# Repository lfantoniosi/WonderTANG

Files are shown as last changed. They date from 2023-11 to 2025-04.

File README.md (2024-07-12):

# WonderTANG
## TangNano 20K cartridge for MSX computers

This cartridge allows any MSX computer to host a Sipeed Tang Nano 20K. The current fpga core implements:

- MicroSD Nextor 2.1 Drive
- FM OPLL + MSX Music ROM
- 2MB Super Mega RAM SCC+
- 4MB Memory Mapper
- Sega Master System VDP + PSG to allow running SMS roms from SofaRun (Franky HDMI)

## The Super Mega RAM SCC+

The Super Mega RAM SCC+ is a different ACVS-like MegaRam that support different mappers:

- Konami4 (2MB)
- Konami5 SCC+ (512KB)
- ASCII8 (2MB)
- ASCII16 (2MB)

Use the utility SMRAM.COM to allow using different mappers as well activating the SCC+, otherwise it will just work like an ordinary MegaRAM 2MB.

## Board Revisions

The latest available version is [V2.0b](#v20av20b-new). Please, use that version to order new boards.

> [!IMPORTANT]
> Always check your board revision when assembling or programming your WonderTANG.
>
> The revision number is available on the front-left side of the board.
>
> Download the specific [FPGA Bitstream version](#fpga-bitstream-versions) required by your board version.

### [V2.0a/V2.0b (NEW)](https://github.com/lfantoniosi/WonderTANG/tree/4a21359a5136a5a96363da55edc5d934acfd37c5/kicad/)

This is the new version using Tang Nano 20K internal DAC amplifier.

Changes since last revision:
* uses internal DAC for audio output
* switches to a flatter audio connector
* removes jumpers
* requires the latest [FPGA bitstream version](#fpga-bitstream-versions)

V2.0a is equivalent to V2.0b.

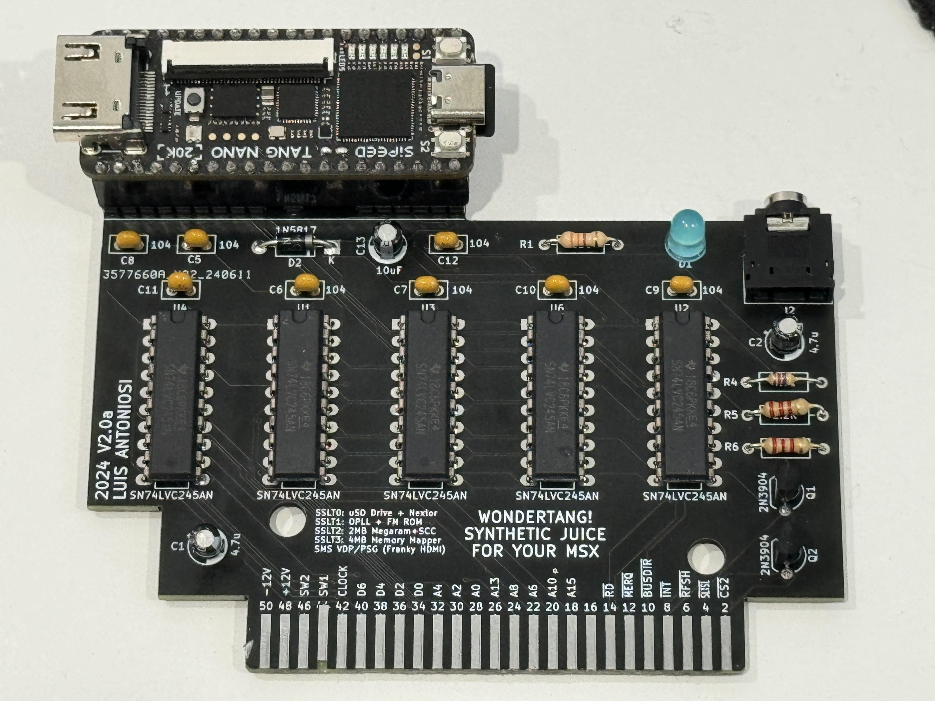
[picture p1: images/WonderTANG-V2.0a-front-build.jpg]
|[](images/WonderTANG-V2.0a-front-build.jpg)|
|:--|
|V2.0a prototype build|

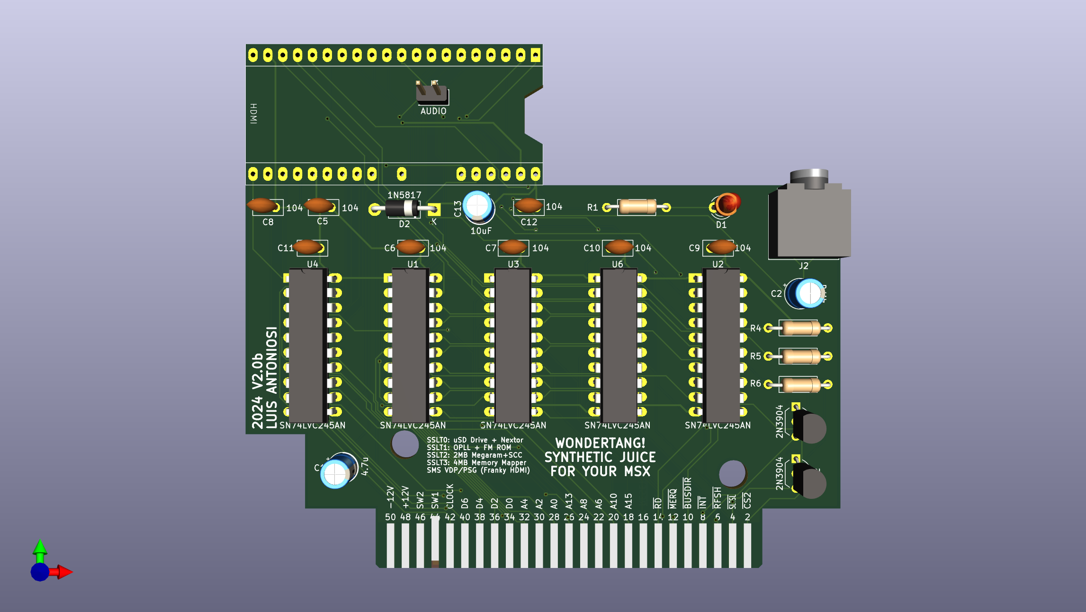
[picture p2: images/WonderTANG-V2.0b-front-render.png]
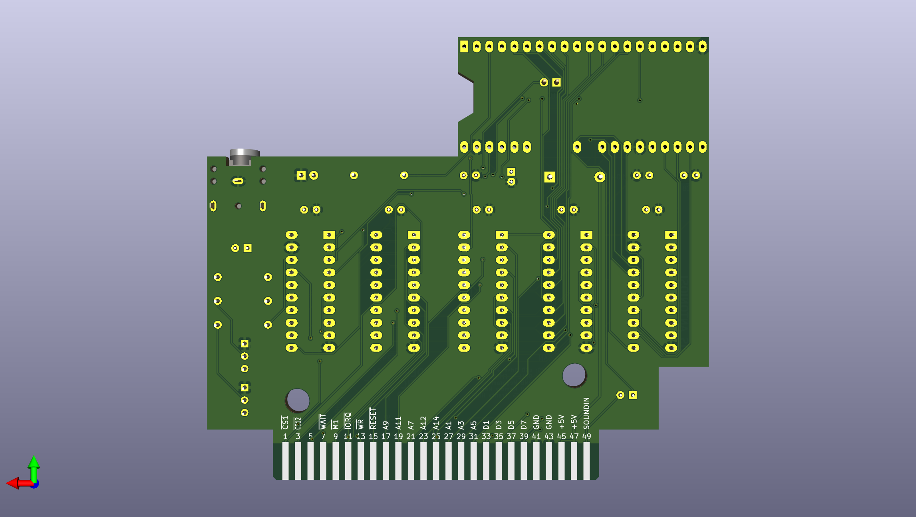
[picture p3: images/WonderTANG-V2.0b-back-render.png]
|[](images/WonderTANG-V2.0b-front-render.png)|[](images/WonderTANG-V2.0b-back-render.png)|
|-|-|
|V2.0b front render|V2.0b back render|

#### PCB

You can access V2.0b gerber files from github at:

[https://github.com/lfantoniosi/WonderTANG/tree/4a21359a5136a5a96363da55edc5d934acfd37c5/kicad/gerber](https://github.com/lfantoniosi/WonderTANG/tree/4a21359a5136a5a96363da55edc5d934acfd37c5/kicad/gerber)

I recommend JLCPCB: https://jlcpcb.com/

#### Bill of Materials

| Reference | Value | Description | Qty | Link |
|---|---|---|-----|---|
| C5, C6, C7, C8, C9, C10, C11, C12 | DIP-100NF | MLCC Monolithic Ceramic Capacitor DIP 100nF (104) | 8 | AliExpress  |
| C1, C2 | ELEC-DIP-4.7UF-16V | Electrolytic Capacitor DIP 4.7uF 16V | 2 | AliExpress  |
| C13 | ELEC-DIP-10UF-16V | Electrolytic Capacitor DIP 10uF 16V | 1 | AliExpress  |
| R5,R6 | DIP-2.2K | Resistor PTH 2.2KR | 2 | Aliexpress  |
| R1 | DIP-330R | Resistor PTH 330R | 1 | AliExpress  |
| R4 | DIP-4.7K | Resistor PTH 4.7KR | 1 | AliExpress  |
| D1 | LED-3MM | LED 3MM Red | 1 | AliExpress  |
| D2 | 1N5817 | SCHOTTKY BARRIER RECTIFIER DIODE | 1 | AliExpress  |
| U1, U2, U3, U4, U6 | SOCKET-DIP-NARROW-20 | DIP Socket Narrow 20 pins | 5 | AliExpress  |
| U1, U2, U3, U4, U6 | SN74LVC245AN | OCTAL BUS TRANSCEIVER WITH 3-STATE OUTPUTS | 5 | See note |
| Q1,Q2 | 2N3904 | 2N3904 NPN switching Transistor | 2 | AliExpress  |
| J2 | CP1-3523N | CONN JACK STEREO 3.5MM R/A | 1 | AliExpress  |
| J3 | Mini Micro male/female JST | Mini Micro male/female JST | 1 | AliExpress  |
| U5 | Tang Nano 20K | Tang Nano 20K | 1 | AliExpress  |

#### Build Notes

The audio J3 needs to be soldered into the TANG Nano 20K speaker pins (two small pins between the words SiPEED and TANG NANO 20K, polarity does not matter). Use the JST connector or solder it directly under the board.

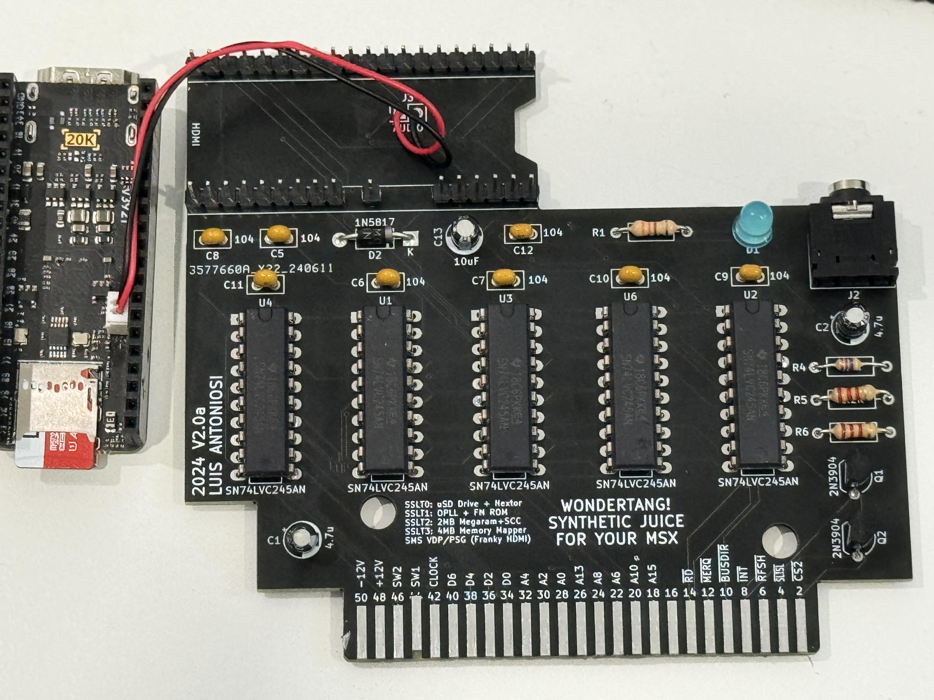
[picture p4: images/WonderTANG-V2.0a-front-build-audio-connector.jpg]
[](images/WonderTANG-V2.0a-front-build-audio-connector.jpg)

#### 74LVC245AN

Be aware of fake 74VLC245 sold from Chinese vendors like AliExpress or UTSource. There are reports of they being 74LS245 rebranded as LVC which does not work. You need genuine 75LVC245. Buy then from DigiKey, Mouser or Adafruit.

### [V1.02d (PREVIOUS)](https://github.com/lfantoniosi/WonderTANG/tree/0e938fb70acad34c753a95fd54bb3fdd6095d590/kicad/)

> [!WARNING]
> If you are building new boards, please use the latest available board revision instead.

This version fixes a problem with Philips MSX machines (detected on [Philips VG8235](https://www.msx.org/wiki/Philips_VG-8235) and [Philips NMS8245](https://www.msx.org/wiki/Philips_NMS_8245)) by properly implementing the MSX cartridge nINT signal as an open-collector.

Changes since last revision:
* uses a transistor to implement nINT as open-collector
* requires a specific [FPGA bitstream version](#fpga-bitstream-versions)

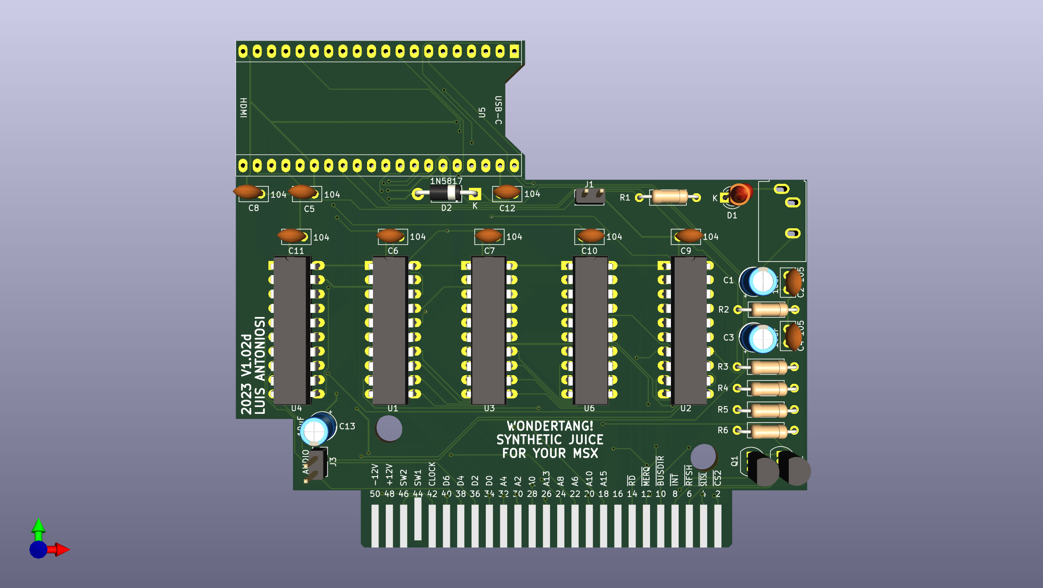
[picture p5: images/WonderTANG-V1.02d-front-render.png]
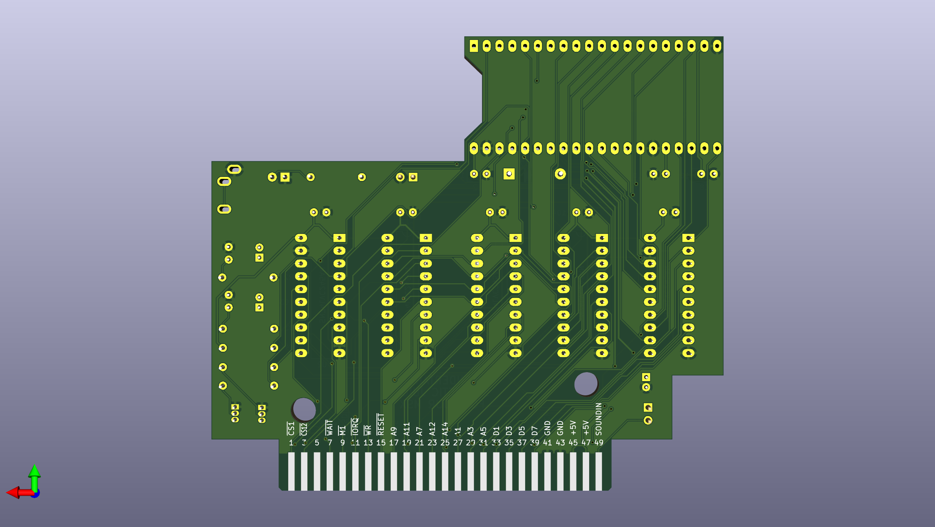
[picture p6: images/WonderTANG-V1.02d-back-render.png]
|[](images/WonderTANG-V1.02d-front-render.png)|[](images/WonderTANG-V1.02d-back-render.png)|
|-|-|
|V1.02d front render|V1.02d back render|

#### PCB

You can access V1.02d gerber files from github at:

[https://github.com/lfantoniosi/WonderTANG/tree/0e938fb70acad34c753a95fd54bb3fdd6095d590/kicad/gerber](https://github.com/lfantoniosi/WonderTANG/tree/0e938fb70acad34c753a95fd54bb3fdd6095d590/kicad/gerber)

#### Bill of Materials

| Reference | Value | Description | Qty | Link |
|---|---|---|-----|---|
| C5, C6, C7, C8, C9, C10, C11, C12 | DIP-100NF | MLCC Monolithic Ceramic Capacitor DIP 100nF (104) | 8 | AliExpress  |
| C1, C3, C13 | ELEC-DIP-10UF-16V | Electrolytic Capacitor DIP 10uF 16V | 3 | AliExpress  |
| C2, C4 | DIP-1UF | MLCC Monolithic Ceramic Capacitor DIP 1uF (105) | 2 | AliExpress  |
| R2, R3 | DIP-47R | Resistor PTH 47R | 2 | AliExpress  |
| R5,R6 | DIP-2.2K | Resistor PTH 2.2KR | 2 | Aliexpress  |
| R1 | DIP-330R | Resistor PTH 330R | 1 | AliExpress  |
| R4 | DIP-4.7K | Resistor PTH 4.7KR | 1 | AliExpress  |
| D1 | LED-3MM | LED 3MM Red | 1 | AliExpress  |
| D2 | 1N5817 | SCHOTTKY BARRIER RECTIFIER DIODE | 1 | AliExpress  |
| U1, U2, U3, U4, U6 | SOCKET-DIP-NARROW-20 | DIP Socket Narrow 20 pins | 5 | AliExpress  |
| U1, U2, U3, U4, U6 | SN74LVC245AN | OCTAL BUS TRANSCEIVER WITH 3-STATE OUTPUTS | 5 | See note above  |
| Q1,Q2 | 2N3904 | 2N3904 NPN switching Transistor | 2 | AliExpress  |
| C13 | ELEC-DIP-10UF-16V | Electrolytic Capacitor DIP 10uF 16V | 1 | AliExpress  |
| C1, C2 | ELEC-DIP-4.7UF-16V | Electrolytic Capacitor DIP 7.7uF 16V | 2 | AliExpress  |
| J1, J3 | PH-254-S-M-40-BLACK | 2.54mm 1 x 40 Pin Male Single Row Pin Header Strip Black | 1 | AliExpress  |
| J2 | SJ1-3533NG | SJ1-3533NG Audio P4 3 Pin connector | 1 | AliExpress  |
| U5 | Tang Nano 20K | Tang Nano 20K | 1 | AliExpress  |

### [V1.01c (OBSOLETE)](https://github.com/lfantoniosi/WonderTANG/tree/b9e608418bb1917098046716af13b877def6737b/kicad/)

> [!WARNING]
> If you are building new boards, please use the latest available board revision instead.

This version corrects an audio problem due to wrong connection of AUDIO and SOUNDIN capacitors.

Changes since last revision:
* fix audio output
* requires an old [FPGA bitstream version](#fpga-bitstream-versions)

> [!IMPORTANT]
> This version is known to experience problems with some Philips MSX machines.

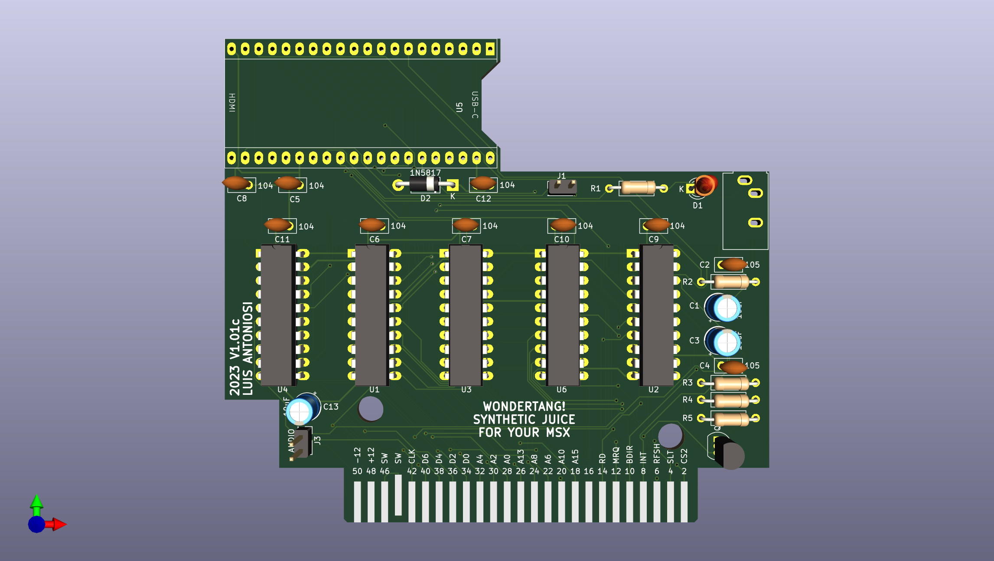
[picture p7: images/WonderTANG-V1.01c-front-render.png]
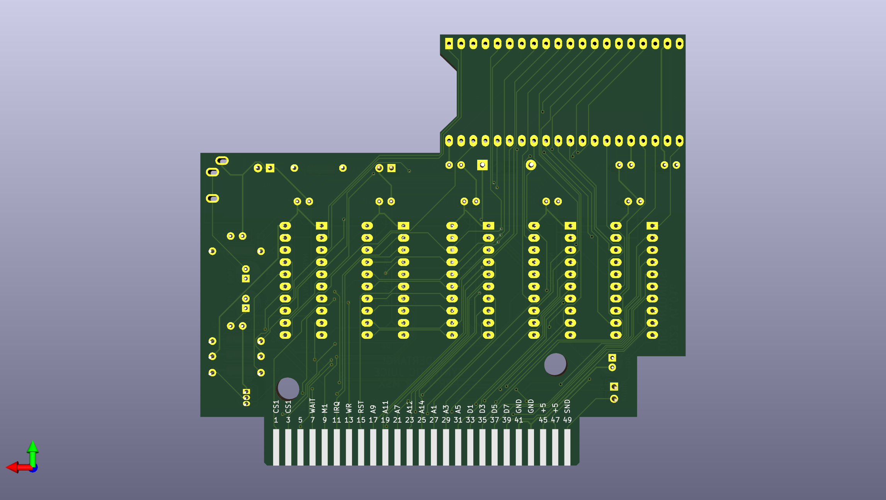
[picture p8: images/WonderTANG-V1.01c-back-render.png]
|[](images/WonderTANG-V1.01c-front-render.png)|[](images/WonderTANG-V1.01c-back-render.png)|
|-|-|
|V1.01c front render|V1.01c back render|

#### PCB

You can access V1.01c gerber files from github at:

[https://github.com/lfantoniosi/WonderTANG/tree/b9e608418bb1917098046716af13b877def6737b/kicad/gerber](https://github.com/lfantoniosi/WonderTANG/tree/b9e608418bb1917098046716af13b877def6737b/kicad/gerber)

Or you can order V1.01c PCBs directly from:

[https://www.pcbway.com/project/shareproject/WonderTANG_v1_01c_ba2c16ea.html](https://www.pcbway.com/project/shareproject/WonderTANG_v1_01c_ba2c16ea.html)

<a href="https://www.pcbway.com/project/shareproject/WonderTANG_v1_01c_ba2c16ea.html">PCB from PCBWay</a>

A small part of the money will be donated to the author of the project.

#### Bill of Materials

| Reference | Value | Description | Qty | Link |
|---|---|---|-----|---|
| C5, C6, C7, C8, C9, C10, C11, C12 | DIP-100NF | MLCC Monolithic Ceramic Capacitor DIP 100nF (104) | 8 | AliExpress  |
| C1, C3, C13 | ELEC-DIP-10UF-16V | Electrolytic Capacitor DIP 10uF 16V | 3 | AliExpress  |
| C2, C4 | DIP-1UF | MLCC Monolithic Ceramic Capacitor DIP 1uF (105) | 2 | AliExpress  |
| R2, R3 | DIP-47R | Resistor PTH 47R | 2 | AliExpress  |
| R1 | DIP-330R | Resistor PTH 330R | 1 | AliExpress  |
| R4 | DIP-4.7K | Resistor PTH 4.7KR | 1 | AliExpress  |
| R5 | DIP-2.2K | Resistor PTH 2.2KR | 1 | |
| D1 | LED-3MM | LED 3MM Red | 1 | AliExpress  |
| D2 | 1N5817 | SCHOTTKY BARRIER RECTIFIER DIODE | 1 | AliExpress  |
| U1, U2, U3, U4, U6 | SOCKET-DIP-NARROW-20 | DIP Socket Narrow 20 pins | 5 | AliExpress  |
| U1, U2, U3, U4, U6 | SN74LVC245AN | OCTAL BUS TRANSCEIVER WITH 3-STATE OUTPUTS | 5 | See note above  |
| Q1 | 2N3904 | 2N3904 NPN switching Transistor | 1 | AliExpress  |
| J1, J3 | PH-254-S-M-40-BLACK | 2.54mm 1 x 40 Pin Male Single Row Pin Header Strip Black | 1 | AliExpress  |
| J2 | SJ1-3533NG | SJ1-3533NG Audio P4 3 Pin connector | 1 | AliExpress  |
| U5 | Tang Nano 20K | Tang Nano 20K | 1 | AliExpress  |

### [V1.01b (OBSOLETE)](https://github.com/lfantoniosi/WonderTANG/tree/09ee5923f52284835864b947fba076c70dbe0fab/kicad/)

### [V1.01 (OBSOLETE)](https://github.com/lfantoniosi/WonderTANG/tree/d6cbb30488c2db2edb72d424ac75a0af0b1afaa3/kicad/)

### [V1.0 (OBSOLETE)](https://github.com/lfantoniosi/WonderTANG/tree/ac242e77184eeba1786766e48963c7b3fef0f877/kicad/)

## FPGA Bitstream Versions

If you want to program your WonderTANG you need to download the specific FPGA bitstream for your board revision according to the following table.

| Board Revision | FPGA Bitstream File |
| --- | --- |
| V1.0 | [WonderTANG_v1.0-v1.01c.fs](https://github.com/lfantoniosi/WonderTANG/blob/main/fpga/impl/pnr/WonderTANG_v1.0-v1.01c.fs?raw=True) |
| V1.01 | [WonderTANG_v1.0-v1.01c.fs](https://github.com/lfantoniosi/WonderTANG/blob/main/fpga/impl/pnr/WonderTANG_v1.0-v1.01c.fs?raw=True) |
| V1.01b | [WonderTANG_v1.0-v1.01c.fs](https://github.com/lfantoniosi/WonderTANG/blob/main/fpga/impl/pnr/WonderTANG_v1.0-v1.01c.fs?raw=True) |
| V1.01c | [WonderTANG_v1.0-v1.01c.fs](https://github.com/lfantoniosi/WonderTANG/blob/main/fpga/impl/pnr/WonderTANG_v1.0-v1.01c.fs?raw=True) |
| V1.02d | [WonderTANG_v1.02d.fs](https://github.com/lfantoniosi/WonderTANG/blob/main/fpga/impl/pnr/WonderTANG_v1.02d.fs?raw=True) |
| V2.0b | [WonderTANG.fs](https://github.com/lfantoniosi/WonderTANG/blob/main/fpga/impl/pnr/WonderTANG.fs?raw=True) |

## Programming the Cartridge

### How to Program the Tang Nano 20K from Windows

Install the Gowin Educative IDE or just the programmer if you want to just flash the files on your board. You can install it from https://www.gowinsemi.com/ by providing your personal data and registering. Please reboot your computer after installing the drivers.

Connect your TangNano board to the computer USB and open the Gowin Programmer software. Please note that we will be just programming the board, so you will not effectively use the IDE at this time. You should see the following message indicating that your board/cable was recognized. 

NOTE: for version 2.0b the FPGA core re-uses JTAG pins. So once flashed to re-flash the tang you need to press S1 button on it before connecting the USB-C cable and keep it pressed during all the time of the flashing process.

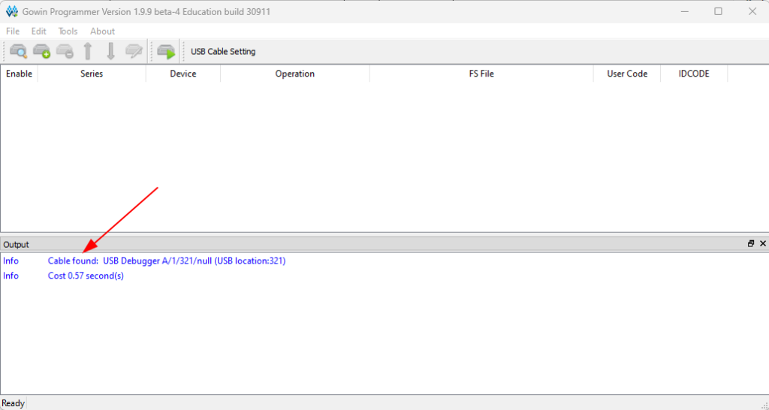
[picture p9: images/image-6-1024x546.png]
Cable Detected


Click Add Device. You will see a new device on the list. Click on the Series and select GW2AR.

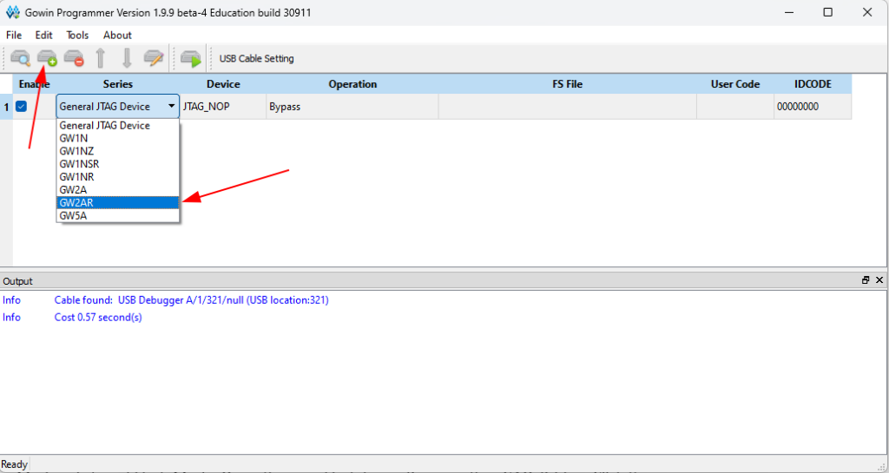
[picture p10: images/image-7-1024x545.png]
Device Selection


Now double click the device on the list and set Access Mode = External Flash Mode, Operation = exFlash Erase, Program thru GAO-Bridge. Click the elipsis and **select the __specific .fs file__ for your WonderTANG board revision** (see [FPGA bitstream versions](#fpga-bitstream-versions)). Select Generic Flash as the Device and make sure the address 0x000000 is selected. Click Save.

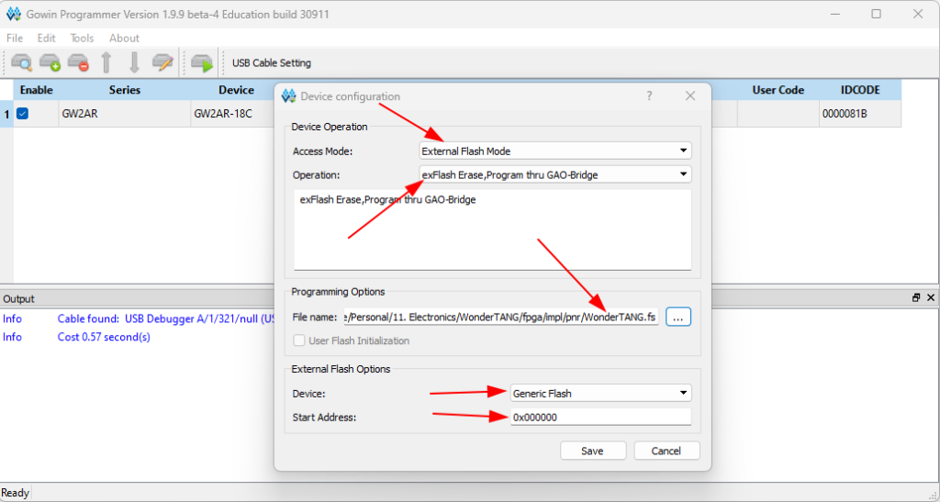
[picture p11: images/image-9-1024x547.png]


Click Add Device again. Set the Series to GW2AR. Double click on the device and set Access Mode = External Flash Mode, select Operation = exFlash C Bin Erase, Program thru GAO-Bridge. Click the elipsis and select the Nextor-2.1.1.WonderTANG.ROM.bin file. Select Generic Flash as the Device and make sure the address 0x100000 is selected. Click Save.

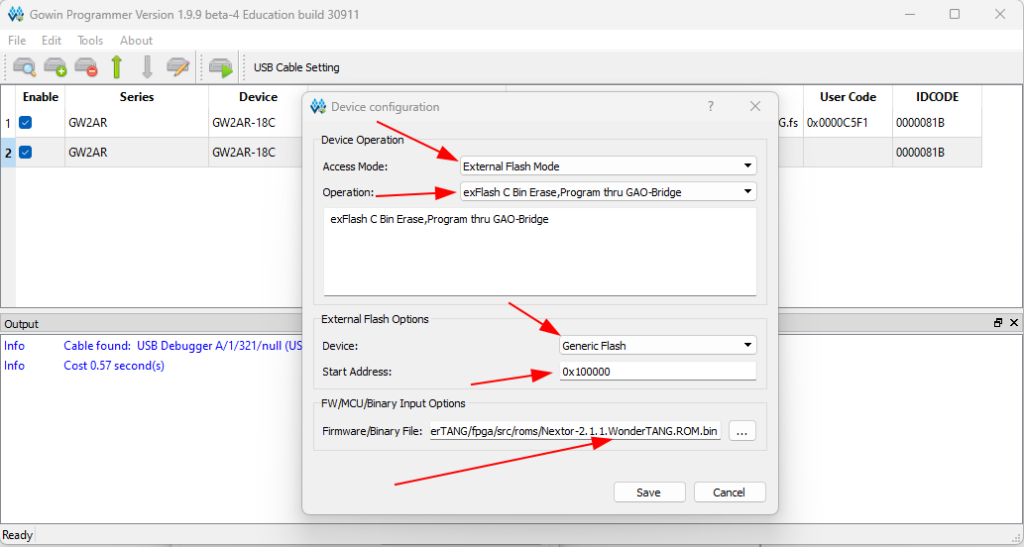
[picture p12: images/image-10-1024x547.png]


Now Enable just the first device on the list, go to the Edit menu and select Program/Configure (or click the program button).

<div style="display: flex; justify-content: space-between;">
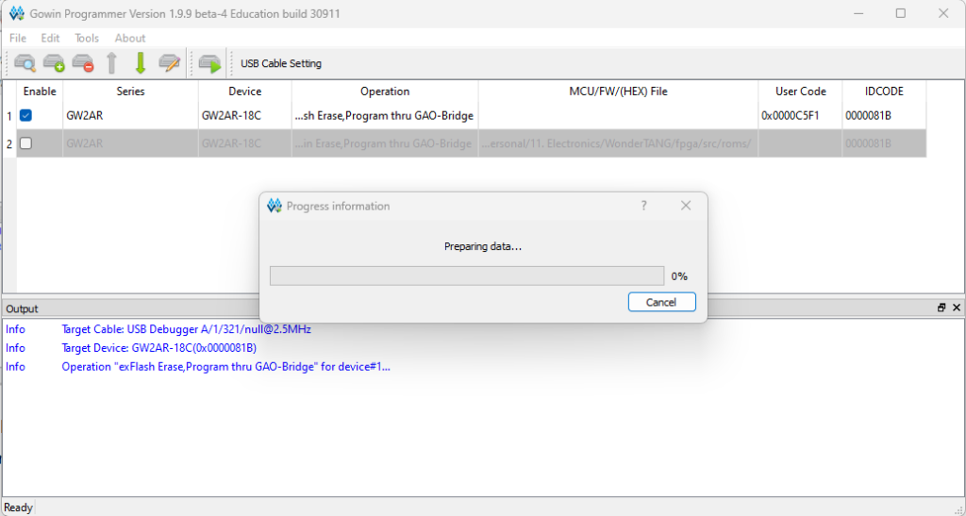
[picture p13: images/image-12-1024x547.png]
     &nbsp;
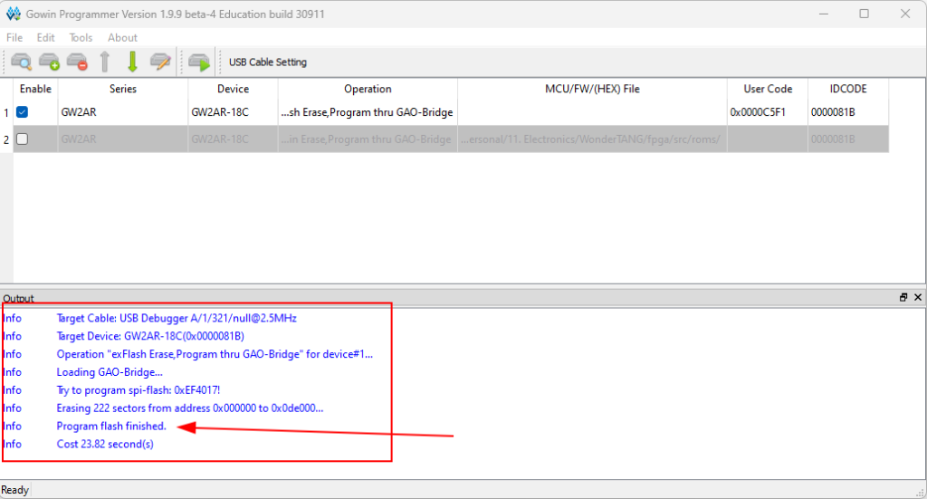
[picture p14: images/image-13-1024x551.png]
    
</div>
&nbsp;

Repeat the steps now enabling just the second device on the list. That will save the BIOS on the flash.

<div style="display: flex; justify-content: space-between;">
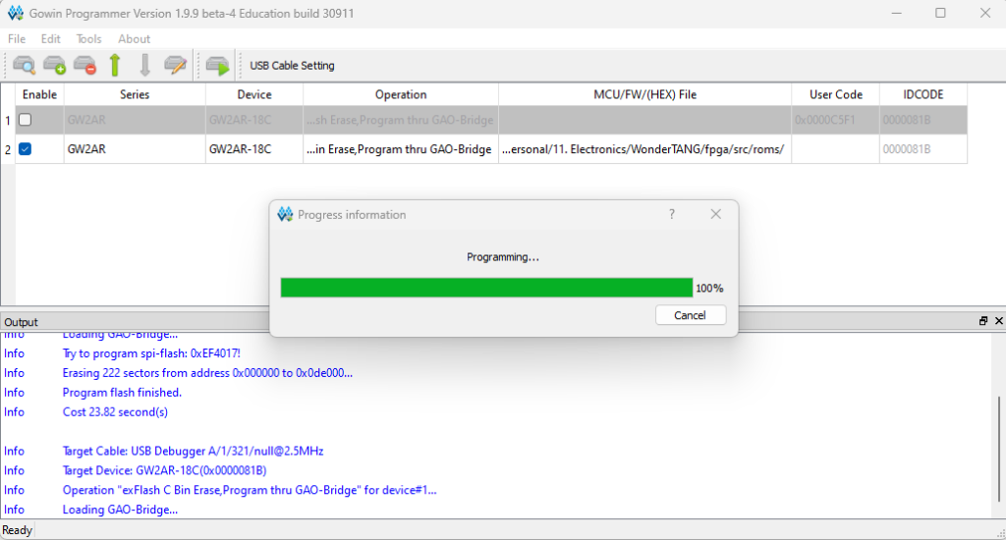
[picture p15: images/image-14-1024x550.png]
     &nbsp;
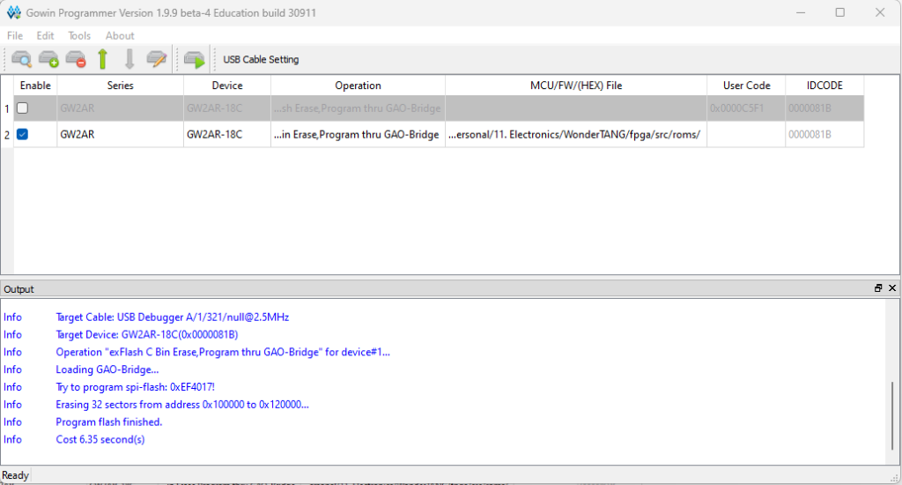
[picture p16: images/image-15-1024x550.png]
    
</div>
&nbsp;

### How to Program the Tang Nano 20K from Linux

As the native programmer of the Gowin IDE does not properly work in Linux, it is recommended to use [openFPGALoader](https://github.com/trabucayre/openFPGALoader) to program the Tang Nano 20K of the WonderTANG.

This procedure has been tested successfully using openFPGALoader v0.10.0.

Assuming that you already downloaded **the __specific .fs file__ for your WonderTANG board revision** (see [FPGA bitstream versions](#fpga-bitstream-versions)) and `Nextor-2.1.1.WonderTANG.ROM` files, and that your Tang Nano 20K is connected to your computer using a USB cable, you can proceed as follows:

* Upload the bitstream (in this case `path_to_your/WonderTANG/fpga/impl/pnr/WonderTang.fs`) using the following command:

```
openFPGALoader -f -b tangnano20k --external-flash path_to_your/WonderTANG/fpga/impl/pnr/WonderTANG.fs
```

* Upload the WonderTANG ROM file `path_to_your/WonderTANG/kernel/Tang/Nextor-2.1.1.WonderTANG.ROM` using the following command:

```
openFPGALoader -f -b tangnano20k --external-flash -o 1048576 path_to_your/WonderTANG/kernel/Tang/Nextor-2.1.1.WonderTANG.ROM
```

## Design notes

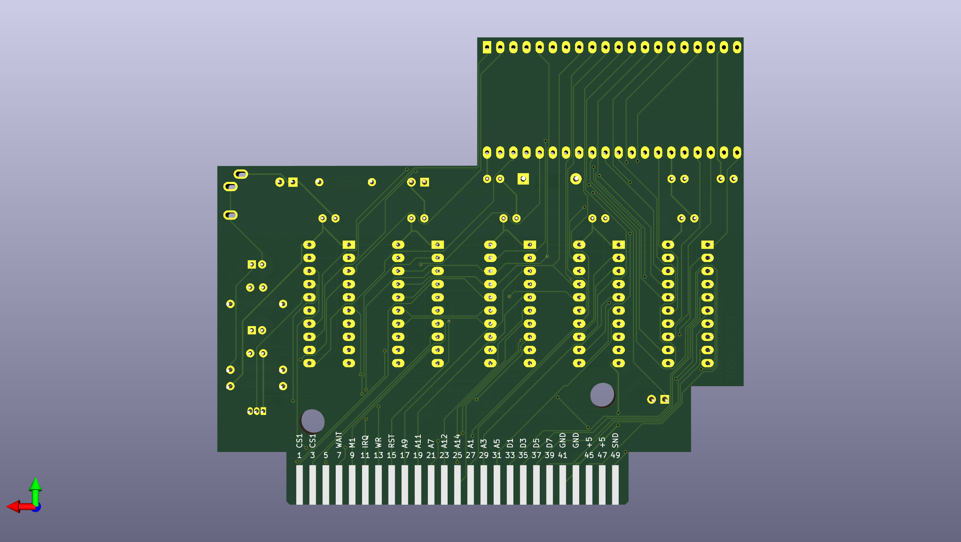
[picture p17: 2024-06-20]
images/WonderTANG-V1.01-back-render.png

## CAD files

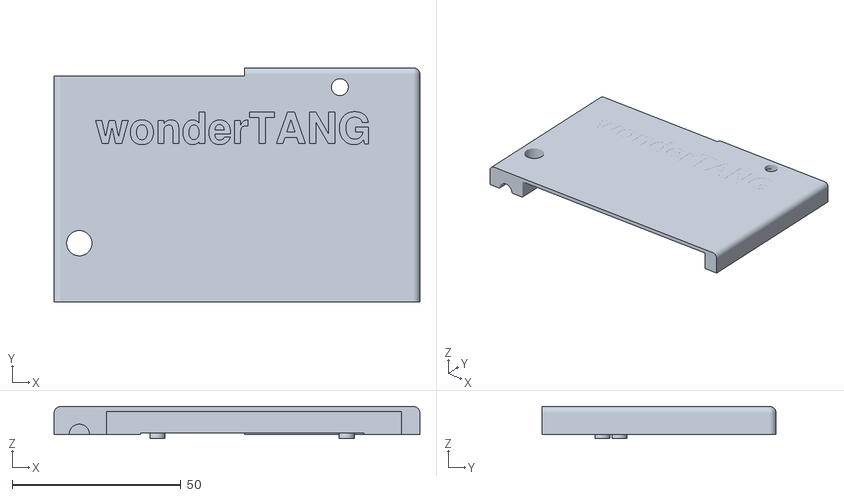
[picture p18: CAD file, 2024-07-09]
case/wonderTANGv2-cart-top.stl
108.5 x 69.5 x 9.50

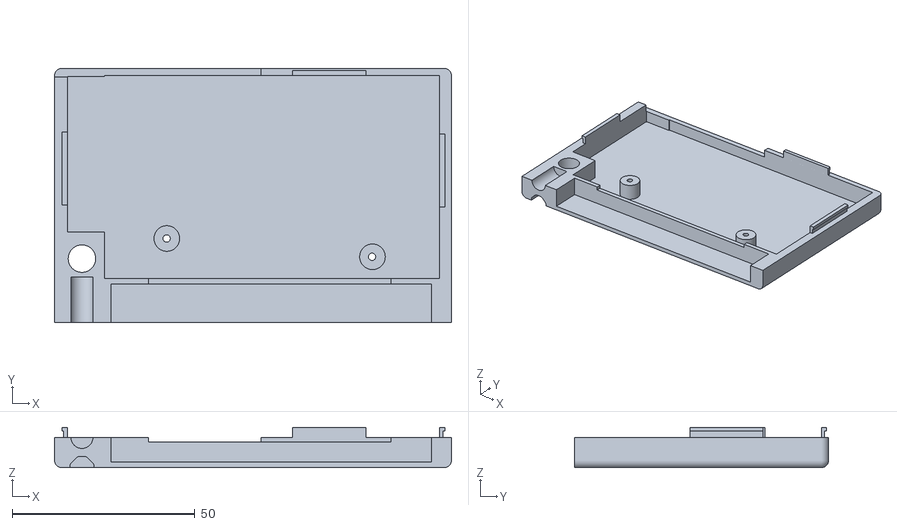
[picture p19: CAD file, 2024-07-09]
case/wonderTANGv2-cart-bottom.stl
108.5 x 69.5 x 11.0

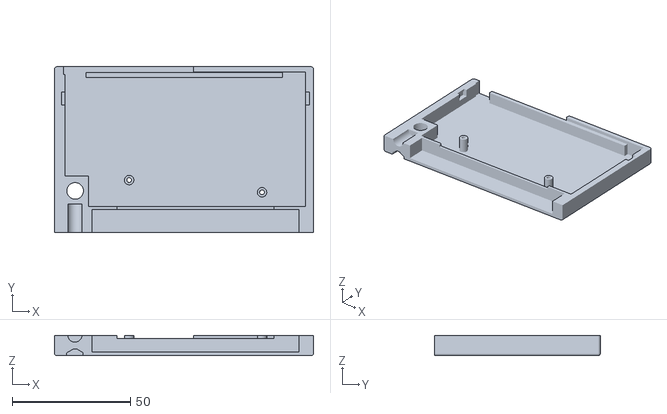
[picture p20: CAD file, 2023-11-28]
case/bottom.stl
109.5 x 70.0 x 8.66

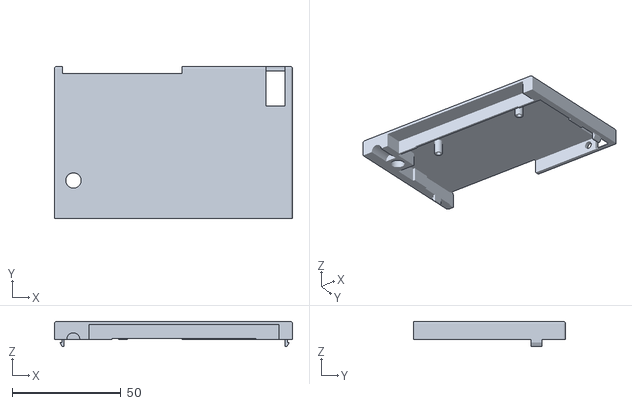
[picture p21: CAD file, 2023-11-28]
case/top.stl
109.5 x 70.0 x 11.6

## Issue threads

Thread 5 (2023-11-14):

sd_reader and BUFG

siriokds, 2023-11-14:
Hi! I wonder if I could use the sd_reader module on a TN9K. The SD card pinout on the 20K has a different pin configuration. What do you think?

Another question is, is BUFG verilog instruction available even on VHDL? Is it a native language feature?

Nice job, thanks.

lfantoniosi, 2023-11-14:
Yes it should work just set map the correct pins.

I don’t know why you want to make a new design in VHDL but yet they are
there. Go for gowin bufg on google and get the pdf from gowin. You l need
to declare the module.

On Mon, Nov 13, 2023 at 10:58 PM Saverio Russo ***@***.***>
wrote:

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

siriokds, 2023-11-14:
> Yes it should work just set map the correct pins. I don’t know why you want to make a new design in VHDL but yet they are there. Go for gowin bufg on google and get the pdf from gowin. You l need to declare the module.
> […](#)
> On Mon, Nov 13, 2023 at 10:58 PM Saverio Russo ***@***.***> wrote: Hi! I wonder if I could use the sd_reader module on a TN9K. The SD card pinout on the 20K has a different pin configuration. What do you think? Another question is, is BUFG verilog instruction available even on VHDL? Is it a native language feature? Nice job, thanks. — Reply to this email directly, view it on GitHub <#5>, or unsubscribe <https://github.com/notifications/unsubscribe-auth/ACCJWU7RYFVLHGRB7T3TNMTYEMJAPAVCNFSM6AAAAAA7KJWXDWVHI2DSMVQWIX3LMV43ASLTON2WKOZRHE4TEMJQHEYTMMQ> . You are receiving this because you are subscribed to this thread.Message ID: ***@***.***>

Thank for quick reply.
I'm not familiar with verilog but 15 years of vhdl. Not yet converted myself to verilog or system verilog.

About SD card, the 9K has only 4 pins connected as far as I saw on the schematic and the DAT1 and DAT2 are not connected.
I don't know if they must be connected to switch to SDIO instead SPI (do your sd_reader uses SDIO ?).

Btw have you faced some design flaw in 9K board? I don't know why but looks a bit noisy.

lfantoniosi, 2023-11-15:
The sd reader uses sdbus, no spi. It's derived from the sd_reader from
internet i just added write routines to it. Some people reported
success using the internet sd reader for 9k so using my version should
not be a problem.

The design flaw is to have HDMI EDID vcc connected to the board VCC.

On Tue, Nov 14, 2023 at 4:27 AM Saverio Russo ***@***.***>
wrote:

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

--
Luis Felipe Antoniosi

siriokds, 2023-11-15:
Probably I will switch to 20K as well, I don't realize if my code isn't
good or it's a board issue.
I need to learn verilog, looks like similar to c-like languages.
I found all documents about gowin primitives thank you.

I used to coding on altera FPGA before the prices rose up

Il mer 15 nov 2023, 09:51 lfantoniosi ***@***.***> ha scritto:

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

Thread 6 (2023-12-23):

How to program Tang Nano 20K

atssada, 2023-12-23:
Hello,

Literally wonderful project you made!
Really appreciated to have a chance to enjoy your masterpiece!

By the way, I am not familiar with Gowin Programmer...

How can I program Wondertang correctly?

Is it enough to program "\fpga\src\roms\Nextor-2.1.1.WonderTANG.ROM.bin"?

I could manage above bin file via Gowin Programmer, but found nothing happened in my MSX(Toshiba HX-10DP, and FS-A1).

I am pretty sure I could solder all necessary parts in the pcb..

Sorry for cumbersome question..

Have a great day!

lfantoniosi, 2023-12-23:
Hi,

You need to program the .fs file inside the impl folder as flash program
generic flash and the the .bin as cbin at address 0x100000 just like is
shown to the readme

The bin file is just the nextor rom not the fpga.

Luis Felipe Antoniosi

On Fri, Dec 22, 2023 at 8:16 PM Jinyong Kim ***@***.***>
wrote:

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

atssada, 2023-12-26:
Thank you very much for kind explanation..

Still I have issue. :)

And this is my reproduction steps, hope you can find any advice..

----

1. Programming WonderTANG.fs

External Flash Mode
exFlash Erase,Program thru GAO-Bridge
Generic Flash
0x000000

2. Programming Nextor-2.1.1.WonderTANG.ROM.bin

External Flash Mode
exFlash Erase,Program thru GAO-Bridge
Generic Flash
0x100000

3. Prepare SD Card

Restore MSX Nextor Bootable VHD image(4GB) to SanDisk 32GB SD Card by using HDD Raw Copy Tool

https://download.file-hunter.com/Archive/MISTICA%20MSX%20VHD%20%5B25-03-2019%5D.zip

https://hddguru.com/software/HDD-Raw-Copy-Tool

4. Insert SD Card To Tang Nano 20K, and power on of MSX..

HDMI TV is showing black screen (turning into black screen from "no-signal")

lfantoniosi, 2023-12-27:
ok I think you are getting some confusion there. First, use a blank SD and
use the call FDISK from basic to create a 4GB partition or smaller.

The hdmi output is *ONLY* for the SMS (MASTER SYSTEM VDP). It won't display
anything for the MSX. For this you use the same output you have.

Check if the msx boots if it shows the wondertang message, detect sd card
and etc.

Once you had the card formatted in FDISK you can copy using a PC the files
to it.

On Mon, Dec 25, 2023 at 4:47 PM Jinyong Kim ***@***.***>
wrote:

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

--
Luis Felipe Antoniosi

cristianoag, 2023-12-30:
Step 2 needs to be Access Mode = External Flash Mode, select Operation = exFlash C Bin Erase, Program thru GAO-Bridge. Click the elipsis and select the Nextor-2.1.1.WonderTANG.ROM.bin file. Select Generic Flash as the Device and make sure the address 0x100000 is selected.

However, I noticed that 1.01 version is driving WAIT to low all the times. Check the transistor and it is shorted to ground with both collector and emitter to GND. Checked the latest circuit and saw there is a 2k2 resistor and a few changes to the transistor footprint connections. Implemented those on my PCB via bodge wires, but no success... the MSX is waiting with WAIT in low all the times. It lookes like the Tang is not executing anything.

lfantoniosi, 2023-12-31:
There was a bug on previous boards. You should follow the new schematic if
you printed an earlier board. The transistor should not have short circuits.

Luis Felipe Antoniosi

On Sat, Dec 30, 2023 at 3:56 PM Cristiano Goncalves <
***@***.***> wrote:

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

cristianoag, 2023-12-31:
I just created a pull request changing the README file to include detailed steps on how to program the Tang Nano. I also included a few images and removed the lock file that was generating a message every time that the project was being opened on kicad. @lfantoniosi upload the gerbers to a shared project on PCBWAY and update the link I included to point to there... you will receive some cash back for your effort. Same with the AliExpress affiliated purchase links.

atssada, 2024-01-13:
@lfantoniosi

Thank you so much for kind additional explanation..

I found my faulty buffer logic ic that I bought from Aliexpress, and I solved the issue with the good ic that I bought from Digikey.

MegaRam, Mapper works flawlessly! Let me enjoy more feature of your wonderful gear.

@cristianoag

Thank you so much for wonderful level of easy & straight forward programming manual. :)

atssada, 2024-01-13:
Thank you so much!

lfantoniosi, 2024-01-13:
glad it is working. check out the sega master system roms from sofarun
ssms.com

I put some patches here:

https://msx.org/forum/msx-talk/general-discussion/franky-ssmscom-patches-where-are-they?page=0

On Fri, Jan 12, 2024 at 5:10 PM Jinyong Kim ***@***.***>
wrote:

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

--
Luis Felipe Antoniosi

Closed 2024-01-13.

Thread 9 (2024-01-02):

TangNano is driving 3.3V on pin 36 (WAIT_33)

cristianoag, 2024-01-02:
The board lokks like is functioning adequately; however, there is a persistent issue with the Tang, consistently delivering 3.3V to pin 36. The transistor, intended to serve as a NOT gate for that line, is erroneously driving GND/0 to the Z80, consequently blocking the proper functioning of the MSX. I have attempted with two TangNano boards without success. Has anyone, aside from Felipe, successfully achieved compatibility with the latest PCB and code versions for this board?

lfantoniosi, 2024-01-02:
what version are you using? there is a pullup resistor for this line (R4).
The tang should put this line to GND. look this line:

assign wait_n = (ff_wait || ~reset_ram_n) ? 1'b1 : 1'b0;

is either 1 or 0. Previous versions of the fpga would put it to Z. You
don't want it to be Z. So use the latest code available.

On Tue, Jan 2, 2024 at 12:53 PM Cristiano Goncalves <
***@***.***> wrote:

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

--
Luis Felipe Antoniosi

lfantoniosi, 2024-01-02:
the wait line is an open collector and should remain GND at startup. So the
transistor opens at the boot and closes forever after disconnecting the line

On Tue, Jan 2, 2024 at 2:05 PM Luis F. Antoniosi ***@***.***>
wrote:

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

--
Luis Felipe Antoniosi

cristianoag, 2024-02-28:
Problem was being caused by bad chips from AliExpress.

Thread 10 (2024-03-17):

Wondertang on the Omega Home Computer

herraa1, 2024-03-17:
First of all thanks a lot for your MSX-related projects, and thanks again for publishing them, I really enjoy them.

Now striaght to the issue...

I've built a WonderTANG and it works wonderfully on most of my real MSX computers (scc, megaram and sms):
- Sony HB-501F OK
- Toshiba HX-10 OK
- Panasonic FS-A1WSX OK
- Sony HB-101P, the boot screen shows up but it looks like the embedded firmware in this machine causes some incompatibility (can reach Basic by pressing CTRL-SHIFT-CODE-GRAPH and then "screen0", but issuing "call system" goes to basic again and again instead of entering Nextor)
- Philips VG-8235, it boots to Nextor prompt but (I'm not sure) either the system freezes or the keyboard doesn't work as can't type anything (I need to do more testing here...)

But trying to use the WonderTANG on my Omega Home Computer always produces problems:
- the boot screen always shows up and recognizes the sd card properly
- but it can get stuck into a boot loop
- or video characters may appear slightly corrupted on the WonderTANG boot screen
- or if it manages to boot properly to nextor, then "call fdisk" terminates after a while if I stop pressing some keys (as if the Esc key was magically pressed)
- or system freezes when accessing the sd card and ends up corrupting it sometimes

I've checked that the WonderTANG receives proper +5V: I have even added a bypass jumper to the diode protecting the MSX from been powered by the USB port from the WonderTANG (I do not power it from USB while inserted on the MSX) to avoid the voltage diode voltage drop (which makes it a bit more stable, but not enough anyway).

My Omega works OK with all software and hardware I've tested (demos, disk games, game cartridges, rookie drive, flashjacks, tsxduino, ...) except for the WonderTANG.

My Omega uses HCT chips as recommended on the official BoM, and has only 512KB of RAM, no RAM extension.
The only addons I have are:
- a floppy disk controller HAT based on the CX-2, but I've uninstalled it with no changes regarding the WonderTANG
- an audio amplifier, but I've disconnected it with no changes regarding the WonderTANG

I don't know where the problem lays between the Omega and the WonderTANG.

Something I've noticed is that when the WonderTANG is inserted into the Omega and I raise a lot the volume of the audio amplifier I can hear a lot more noises than the "usual" ones from the Omega when no WonderTANG is inserted.

Have you tried your WonderTANG on your Omega Home Computer?
Does it work for you?
Any clues on why mine's doesn't properly work?

Thanks a lot!

lfantoniosi, 2024-03-18:
I didn't try because my omega is without a power supply.

If you look to any MSX implementation the wait line connects directly to
the Z-80 halting it when low. On omega it goes to a SLPD (slot dir) where
it adds VDP wait, KDB wait and M1 wait.

Wait is an open collector, I don't know if this SPLD is preserving it. I
didn't look ot other MSX2+ implementations to compare.

Luis Felipe Antoniosi

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

lfantoniosi, 2024-03-18:
Can you disconnect the wait line (remove transistor) and test it on both
machines?

Luis Felipe Antoniosi

On Sun, Mar 17, 2024 at 10:41 PM Luis F. Antoniosi <
***@***.***> wrote:

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

herraa1, 2024-03-18:
I desoldered the transistor Q1 and tried again with the Toshiba HX-10 and the Omega.

The Toshiba HX-10 no longer works ok (it behaves now like the Sony HB-101P in the previous test):
- the system boots and shows the WonderTANG boot info, detecting the SD card
- it asks for the date and enters Basic
- the Basic info shows that there is MSX Basic 1.0 and Disk Basic 1.0 (so the WonderTANG adds the disk Basic)
- when you try a "call system" it re-enters Basic again, no Nextor
- if you try a "files" it displays "Disk I/O error" and returns to the Basic prompt

The Omega doesn't work either.
- the system boots and shows the WonderTANG boot info, detecting the SD card
- sometimes it freezes during the boot process
- sometimes it manages to load Nextor
- sometimes it boots to basic instead of Nextor
- if it manages to load Nextor, a "dir" completes correctly (shows files, shows space free and returns to DOS prompt) but trying to load a ROM with SMRAM.COM shows "ERROR Super MegaRAM SCC+ not found..." Also loading commands from SD card works (I loaded HIDTEST.COM for example, it worked and returned to DOS prompt correctly)

Thanks.

herraa1, 2024-03-19:
I've looked at the available schematics for my MSX computers.
(I couldn't find one for the Toshiba HX-10, but according to this article https://www.cuadernoinformatica.com/2021/05/toshiba-msx-hx-10-64k-electronica.html the ToshibaHX-10 uses a TCX-1007 custom MSX engine which generates the wait signal for the CPU and a flip-flop is also involved).

This is what I saw:
- Sony HB-101P pulls up the slot wait signal coming from the slots using a 10KOhm resistor and then uses the M1 signal through a flip-flop and an AND gate to generate the wait signal for the CPU
- Sony HB-501F uses a MSX engine, no explicit pull-up for the slot wait signal
- Toshiba HX-10 (see above)
- Philips VG8235 pulls up the slot wait signal coming from the slots using a 680 Ohm resistor before connecting it to the CPU wait pin
- Panasonic FS-A1WSX seems to pull-up with a 22KOhm resistor the wait signal on the MSX Engine chip
- Omega, no pull-up on the wait signal coming from the slots before entering the GAL

So maybe the problem with the Omega is that the slot wait signal is not consistent because the Omega has no pull-up for the slot wait signal and the WonderTANG leaves it floating when not pulled to GND.

Does it make sense to you?

Thanks.

lfantoniosi, 2024-03-19:
It does the wait slot has a pullup before the spld

Luis Felipe Antoniosi

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

herraa1, 2024-03-19:
Oh, yes, I missed the resistor array RR5 on the schematic...

So, back to square one.

herraa1, 2024-03-24:
Hi,

I resoldered the Q1 transistor and tested again with same original results.

I did more tests with the Sony HB-101P and found that it is indeed the embedded firmware that causes issues. The WonderTANG works OK on the Sony HB-101P but the embedded firmware seems to force a boot in MSX-DOS 1 mode (loading MSXDOS.SYS and COMMAND.COM), so a FAT12 partition must be present in the SD-CARD in order for this to work. I didn't manage to boot in Nextor mode (tried to bypass firmware with the key combo and even with a Flashjacks, but no way), so usage is very limited, but access to files in the SD card works flawlessly.

The Philips VG-8235 freezes (as did originally) at the A:> prompt after loading Nextor (does the same when forcing boot into MSX-DOS 1 mode). I say it freezes because keyboard does not work and the caps lock led does not light up.
It works Ok without the WonderTANG, or with a Flashjacks.

The Omega continues to exhibit the same random behaviour and errors with the WonderTANG, no matter what.

Thanks.

Papipapito, 2024-05-02:
Hello, I have the same problem with an 8235, mine has the bios changed to use the 720 floppy drive, it starts loading nextor or exits to basic, but the keyboard does not work
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

herraa1, 2024-05-22:
The WonderTANG works fine on the Omega since #15 so I think that we can close this issue, and move the Philips VG8235 issue to new one to make things clear.

Closed 2024-06-12.

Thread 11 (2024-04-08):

Wrong link to PCBWay?

m6502, 2024-04-08:
I get an error by following the PCBWay link:

https://www.pcbway.com/project/shareproject/TangNano_20K_Cartridge_for_MSX.html

After a small search it looks like the right link would be: https://www.pcbway.com/project/shareproject/WonderTANG_v1_01c_ba2c16ea.html

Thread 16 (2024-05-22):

WonderTANG on the Philips VG8235

herraa1, 2024-05-22:
When trying to use the WonderTANG on a Philips VG8235 two problems have been observed:
- problem 1 is that on every power on (not reboot) the caps led turns on briefly and the cassette relay clicks briefly too
- problem 2 is that the Philips VG8235 freezes on boot after loading Nextor (or MSXDOS) and shows an A:> prompt even if there is an autoexec.bat present on boot media. It freezes too if the boot media does not contain Nextor nor MSXDOS and the system boots to Basic and shows a "Ok" prompt even if there is an autoexec.bas present on inserted media.

Problem 1 is still been investigated and it is thought to be related to the initial electrical state of the tn20k signals just immediately after power on.

Problem 2 has been traced down to a problem in the current board design which incorrectly handles nINT (edge cartridge connector pin 8) as a push-pull output when it should be an open collector output.
Although this board design mistake does not prevent many MSX machines from working correctly with the WonderTANG as is, the Philips VG8235 can't keep the nINT signal HIGH if a WonderTANG is inserted and thus nINT is asserted continuously and the machine freezes.

herraa1, 2024-05-22:
See screenshots of problem 2 on comment from user Papipapito in a different [issue](https://github.com/lfantoniosi/WonderTANG/issues/10#issuecomment-2089945752)

herraa1, 2024-05-23:
Finally, after proper testing, the root cause for problem 1 has been identified.

It is not related to the electrical state of the tn20k but it is caused by the WonderTANG holding the nWAIT signal during boot until it is ready for service, which prevents the Z80 from executing the BIOS code for a second or so, and in particular the code that initializes the S3527 msx-system/msx-engine (which, as seen in the Philips VG-8235/00 service manual, is in charge of the "CAPS LED DRIVER" which manages the CAPS led, and the "CASSETTE REMOTE CONTR" which manages the cassette relay).
After power up and without the msx-engine initialized, the CAPS led seems to be lit by default and the cassette relay energized.

Closed 2024-06-12.

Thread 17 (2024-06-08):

SCC sound

polileco, 2024-06-08:
Hi,

Tks for the great work.

Is the SCC audio injected back into the bus? Here I can only hear the SCC sound through the P2 or HDMI output.

Regards

lfantoniosi, 2024-06-12:
yes but to faint to be seen. the new incoming 2.0a version will fix this but requires new board.

Closed 2024-06-12.

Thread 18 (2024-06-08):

Multiples config

polileco, 2024-06-08:
Hello,

It's possible to have a file to config the sub slots at boot time like we have in some OCM machines? Or at least use one of the buttons on Tang to disable all?

Tks

lfantoniosi, 2024-06-12:
the FPGA cannot read a file from the SD there is no active CPU/OS running there.

Closed 2024-06-12.

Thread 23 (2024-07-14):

WonderTANG sound noises

herraa1, 2024-07-14:
The WonderTANG sound output is currently affected by several sources of noise.
This issue is here to try to identify those sources of noise and maybe help fixing some of them.

The issue will be about WonderTANG 2.0 (which uses the tn20k DAC for sound output), but references to other versions for comparison purposes will be documented.

Observation 1: If you severe/open the track that feeds sound into the MSX (vía the SOUNDIN cartridge pin), and thus WonderTANG sound is disconnected from the MSX sound, you can observe that noises are present too in the native MSX computer audio port (like for example the easily identifiable click, click, click sound). The native MSX sound volume is way lower than the WonderTANG audio output volume so in order to hear the native MSX sound noises you need to raise the volume of the amplifier where the MSX sound output is connected.

Observation 2: Sometimes a high pitched noise can be heard on the WonderTANG audio output. This high pitched noise can be heard only when the WS2812 LED in the Tang Nano 20k is lit.

Observation 3: There is a continuous click, click, click noise (of about 220-230 bpm) on the WonderTANG audio output. This noise can be heard too on the native MSX sound output (even when SOUNDIN is not connected). This noise is not present when the WonderTANG cartridge is not inserted into an MSX cartridge slot.

Observation 4: There is a continuous "white noise" on the WonderTANG audio output.

Observation 5: The noises are present on WonderTANG 2.0 and also on earlier versions of the board that did not use the DAC for sound output.

Observation 6: Some noises are present in the HDMI sound output too (specially the click, click, click noise). This has been checked by using an hdmi video capture card which can extract hdmi audio to a jack output and connecting the jack output to an audio mux (with just that input connected) and then to headphones. Note that if I connect the headphones directly to the hdmi video capture card, the noises can't be barely heard. It is assumed that either the hdmi capture card audio jack output behaves differently when connecting headphones or a line signal, or simply that when connecting the headphones directly the default audio volume does not permit to hear the noises.
(The hdmi capture card was powered by an independent linear lab power supply to discard possible switching interferences).

herraa1, 2024-07-14:
If we take observation 6 into account, and keeping in mind that the HDMI sound is sent in digital format, if the click,click,click sound is present in the HDMI sound output then it should be present in the digital sound wave that is fed into the HDMI ip.
This could explain why the click,click,click sound is present too in both the WonderTANG 2.0 DAC-based sound  and the previous WonderTANG (which do not use the DAC).
The click,click,click sound is observed in the WonderTANG 2.0 output immediately on the tn20k speaker outputs (without going through the WonderTANG board).

On the other hand, if we can hear the click,click,click noise on the native MSX audio while having the SOUNDIN disconnected then it cannot be related only to the digital sound wave.

There must be something that can explain both observations.
Maybe the click,click,click noise ends up appearing in both cases through different ways.

lfantoniosi, 2024-07-14:
No the click sound is not in the sound wave, in fact you can nullify it and output plain 0's and the click still there. There is a lot of internal cross talk, any access to SD results in white noise and in the version 2.0 I turn off the RGB led to avoid its interference, but the repeated click click I believe is due to the uncertainty of the tang output, tang seems to not being able to keep the clocks steady and this ends up creating a ripple effect in any output. Unfortunately, ripple on the audio output results in noise.

herraa1, 2024-07-18:
> No the click sound is not in the sound wave, in fact you can nullify it and output plain 0's and the click still there. There is a lot of internal cross talk, any access to SD results in white noise and in the version 2.0 I turn off the RGB led to avoid its interference, but the repeated click click I believe is due to the uncertainty of the tang output, tang seems to not being able to keep the clocks steady and this ends up creating a ripple effect in any output. Unfortunately, ripple on the audio output results in noise.

Yes, I did the test of zeroing the sound wave just before you posted about it, and indeed, the click,click,click noise is still there.

I can understand the given explanation for an analog output, like SOUNDIN or the jack output of the WonderTANG.
But how can the click,click,click noise infiltrate the digital audio signal transferred via the HDMI connector? And even more difficult yet, how can it affect it producing the same click,click,click noise as in the analog outputs?

Could it be affecting both GND and signals, and end up manifesting due to the distortion in GND?
If that's the case, then maybe using a GND isolator between the WonderTANG HDMI connector and the HDMI receiver would remove the noise, wouldn't it?

lfantoniosi, 2024-07-18:
I think it depends on the hdmi codec quality. The codec expects a steady
44100Hz encoding and if the tang fails to deliver on time, the codec might
as well fail or glitch, even desync and lose audio.

I have a Samsung 1440p monitor and it has headphone output. I can crank it
to maximum and I don't hear a click.

Btw, I have this passive HDMI/VGA conversor that uses the hdmi power and
there the audio jack has the click click.

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

--
Luis Felipe Antoniosi

herraa1, 2024-07-18:
I just did the same test with one of my old Dell monitors (2408WFP) which has an HDMI input and audio jack output.
I fed the WonderTANG HDMI to the monitor and connected the jack audio output from the monitor to my soundsticks with volume at max, and, yes, in this particular case absolutely no noises!

Then I re-tested some previous scenarios with my 4K USB3.0 HDMI video capture device which has an HDMI input, HDMI output, jack audio output and USB (and which gets power from USB, because when I disconnect the USB while having the HDMI input connected, the device powers off).

When getting sound directly via the jack output or USB of the video capture card, there are no noises present, never.
But if I connect the jack audio output via a 4-way external audio selector, then I can hear noises. But guess what... they do not come in this case from the WonderTANG... they come from my desktop PC via the monitor audio jack or the line out from the PC which are connected too to the 4-way external audio selector. And the noise appears even if the monitor audio jack channel or the line in audio channel are not selected.
I ended up discovering that by disconnecting all the audio channels except the one used for the video capture card! In that case I have no noises either.

So that's why when getting audio from HDMI using the Dell 2408WFP monitor (which is not connected to anything except the WonderTANG) produced no noises...

My other Dell monitor has Display Port input (where I connect my PC) and HDMI input where I connect MSX via several devices, depending on the particular MSX native output. It has too an audio jack output.
In the tests where I could hear the WonderTANG noises via HDMI using my USB capture card, I had my PC connected via DP and my Toshiba MSX connected via an RCA-to-HDMI powered by USB (from my PC!) so I guess my PC was getting the noise from the RCA-to-HDMI via USB and contaminating the audio output of the 4-way external audio selector via the HDMI and/or line in channels.

So that would end up making sense as the digital audio output integrity was always preserved, but the noises came indirectly.

So... If you want to have the better noise-less audio from the WonderTANG, get it from the HDMI output.
(In case someone didn't notice it, all audio gets to the HDMI output, not just the SMS audio).

herraa1, 2024-08-18:
Closing the issue as it seems that the audio analog outputs can't be improved with the current hardware, and the digital output is confirmed noiseless.

Closed 2024-08-18.

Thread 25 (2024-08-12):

More Omega issues

JmanNZ, 2024-08-12:
Hi
My MSX is an Omega with the ram expansion removed.
I am using PCB version V2.0b with the WonderTANG.fs firmware from here.
Nextor-2.1.1.WonderTANG.ROM.bin is installed.

With the WonderTang in either slot i only get a black screen with what seems to be extra current draw from the PSU. (Bench PSU with meters).
If i remove the Nano20k the system starts as normal and current draw is normal.
With the Nano20K installed and U4 removed the system starts as normal and the current draw is normal + extra for the WonderTang.

74LVC245's are originals from Element14.
I have checked the PCB for any shorts but cannot see any.
The wait signal does toggle (U4 removed)

Any help would be greatly appreciated
Thank you

JmanNZ, 2024-08-13:
It works :)
turned out to be low voltage via DC connector. Removed the connector add 5V directly to the PCB and success.
Thank You

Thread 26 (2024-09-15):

There is one or more SCC channels that are not sounding.

yukky37, 2024-09-15:
I compared the SCC sound with the original cartridge and WonderTANG! 2.0b and found that there is a channel somewhere that is not sounding. It is easily found at the beginning of stage 2 of Salamander and I am attaching a video to confirm.
SCC emulation may be incomplete.
https://x.com/Yukky37x/status/1830628831952310298

Since tnCart with 1.02d hardware sounds fine, it is possible that there is an issue with the software.
https://x.com/Yukky37x/status/1832428187659227521

I posted this on the msx.org forum and others have had similar experiences, so I have registered this issue here.
https://www.msx.org/forum/msx-talk/hardware/wondertang-who-wants-to-juice-up-your-msx?page=45

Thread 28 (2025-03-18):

only 512k MegaRam

steswart, 2025-03-18:
Why am I only seeing 512K MegaRam? This is both on my 738 with a Go'ahuld and an Omega MSX

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

rafaelan00, 2025-03-19:
same problem.

lfantoniosi, 2025-03-19:
The Konami SCC Megaram supports only 512KB as per specifications.

To use as megaram 2MB you need to use the SMRAM.COM but it won't support
SCC.

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

--
Luis Felipe Antoniosi

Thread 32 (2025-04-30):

ordering som pcbs from the gerbers and pcbway keep asking questions

soviet9922, 2025-04-30:
Hi sorry to ask but i'm not sure what is the correct option.
Ordered the wondertang pcbs using the gervers here:
https://www.pcbway.com/project/shareproject/WonderTANG_2_0b_Latest_version_MSX_FPGA_Cartridge_057d0218.html

And got this question from pcbway:
Engineering question:
For this finger area designed on board, there is soldermask bridge between each two of the finger pads, please advise if you want us just produce the board according to the original file? Or we need to apply complete soldermask openings on finger area(the soldermask bridge will be removed) like what shown in the attached picture?

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

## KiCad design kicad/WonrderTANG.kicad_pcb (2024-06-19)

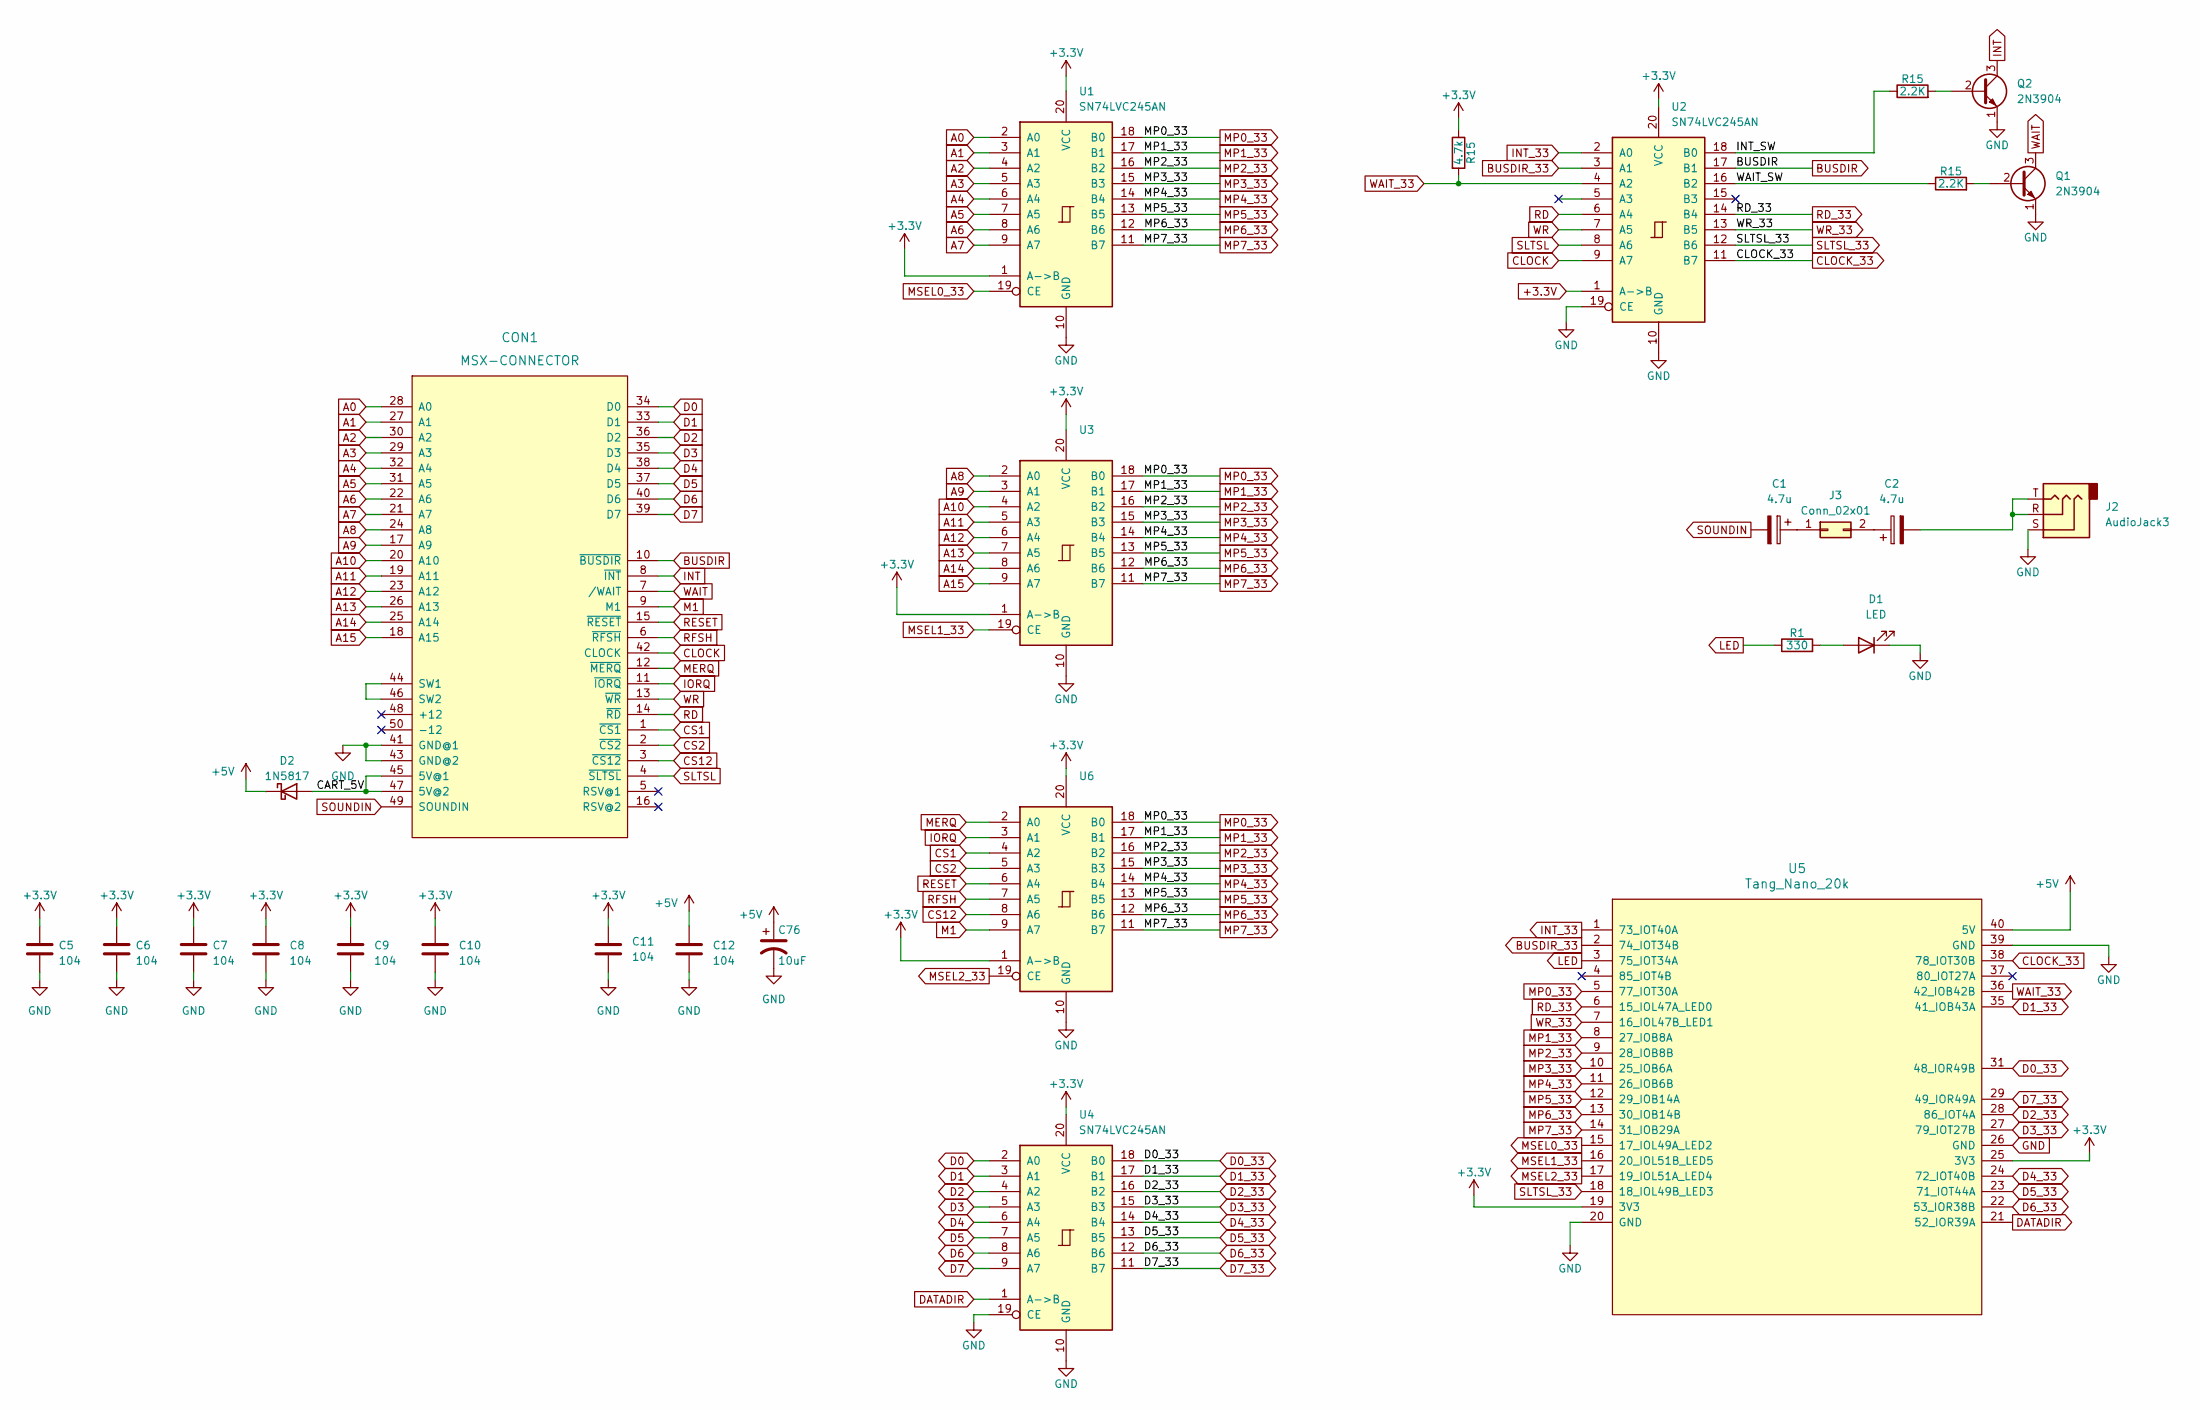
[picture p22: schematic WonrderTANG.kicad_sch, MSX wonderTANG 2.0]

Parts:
C1, C2: 4.7u; CP_Radial_D5.0mm_P2.50mm
C5, C6, C7, C8, C9, C10, C11, C12: 104; C_Disc_D5.0mm_W2.5mm_P2.50mm
C76: 10uF; CP_Radial_D5.0mm_P2.00mm
CON1: MSX-CONNECTOR; CARTRIDGE_MSX_NOCUT
D1: LED; LED_D3.0mm
D2: 1N5817; D_DO-41_SOD81_P10.16mm_Horizontal
J2: AudioJack3; SJ1-3523N
J3: Conn_02x01; PinHeader_2x01_P2.54mm_Vertical
Q1, Q2: 2N3904; TO-92_Inline_Wide
R1: 330; R_Axial_DIN0207_L6.3mm_D2.5mm_P10.16mm_Horizontal
R15: 2.2K; R_Axial_DIN0207_L6.3mm_D2.5mm_P10.16mm_Horizontal
U1, U2, U3, U4, U6: SN74LVC245AN; DIP-20_W7.62mm_LongPads
U5: Tang_Nano_20k; Tang_Nano_20k_Audio

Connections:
+3.3V: C5.1, C6.1, C7.1, C8.1, C9.1, C10.1, C11.1, U1.1 (A->B), U1.20 (VCC), U2.1 (A->B), U2.20 (VCC), U3.1 (A->B), U3.20 (VCC), U4.20 (VCC), U5.19 (3V3), U5.25 (3V3), U6.1 (A->B), U6.20 (VCC); also elsewhere on the board
+5V: C12.1, D2.1 (K), U5.40 (5V); also elsewhere on the board
/CART_5V: CON1.45 (5V@1), CON1.47 (5V@2), D2.2 (A)
/INT_SW: U2.18 (B0); also elsewhere on the board
/WAIT_SW: U2.16 (B2); also elsewhere on the board
A0: CON1.28 (A0), U1.2 (A0)
A1: CON1.27 (A1), U1.3 (A1)
A2: CON1.30 (A2), U1.4 (A2)
A3: CON1.29 (A3), U1.5 (A3)
A4: CON1.32 (A4), U1.6 (A4)
A5: CON1.31 (A5), U1.7 (A5)
A6: CON1.22 (A6), U1.8 (A6)
A7: CON1.21 (A7), U1.9 (A7)
A8: CON1.24 (A8), U3.2 (A0)
A9: CON1.17 (A9), U3.3 (A1)
A10: CON1.20 (A10), U3.4 (A2)
A11: CON1.19 (A11), U3.5 (A3)
A12: CON1.23 (A12), U3.6 (A4)
A13: CON1.26 (A13), U3.7 (A5)
A14: CON1.25 (A14), U3.8 (A6)
A15: CON1.18 (A15), U3.9 (A7)
BUSDIR: CON1.10 (~BUSDIR), U2.17 (B1)
BUSDIR_33: U2.3 (A1), U5.2 (74_IOT34B)
CLOCK: CON1.42 (CLOCK), U2.9 (A7)
CLOCK_33: U2.11 (B7), U5.38 (78_IOT30B)
CS1: CON1.1 (~CS1), U6.4 (A2)
CS2: CON1.2 (~CS2), U6.5 (A3)
CS12: CON1.3 (~CS12), U6.8 (A6)
D0: CON1.34 (D0), U4.2 (A0)
D0_33: U4.18 (B0), U5.31 (48_IOR49B)
D1: CON1.33 (D1), U4.3 (A1)
D1_33: U4.17 (B1), U5.35 (41_IOB43A)
D2: CON1.36 (D2), U4.4 (A2)
D2_33: U4.16 (B2), U5.28 (86_IOT4A)
D3: CON1.35 (D3), U4.5 (A3)
D3_33: U4.15 (B3), U5.27 (79_IOT27B)
D4: CON1.38 (D4), U4.6 (A4)
D4_33: U4.14 (B4), U5.24 (72_IOT40B)
D5: CON1.37 (D5), U4.7 (A5)
D5_33: U4.13 (B5), U5.23 (71_IOT44A)
D6: CON1.40 (D6), U4.8 (A6)
D6_33: U4.12 (B6), U5.22 (53_IOR38B)
D7: CON1.39 (D7), U4.9 (A7)
D7_33: U4.11 (B7), U5.29 (49_IOR49A)
DATADIR: U4.1 (A->B), U5.21 (52_IOR39A)
GND: C5.2, C6.2, C7.2, C8.2, C9.2, C10.2, C11.2, C12.2, CON1.41 (GND@1), CON1.43 (GND@2), D1.1 (K), J2.S, Q1.1 (E), Q2.1 (E), U1.10 (GND), U2.10 (GND), U2.19 (CE), U3.10 (GND), U4.10 (GND), U4.19 (CE), U5.20 (GND), U5.26 (GND), U5.39 (GND), U6.10 (GND); also elsewhere on the board
INT: CON1.8 (~INT), Q2.3 (C)
INT_33: U2.2 (A0), U5.1 (73_IOT40A)
IORQ: CON1.11 (~IORQ), U6.3 (A1)
LED: R1.1, U5.3 (75_IOT34A)
M1: CON1.9 (M1), U6.9 (A7)
MERQ: CON1.12 (~MERQ), U6.2 (A0)
MP0_33: U1.18 (B0), U3.18 (B0), U5.5 (77_IOT30A), U6.18 (B0)
MP1_33: U1.17 (B1), U3.17 (B1), U5.8 (27_IOB8A), U6.17 (B1)
MP2_33: U1.16 (B2), U3.16 (B2), U5.9 (28_IOB8B), U6.16 (B2)
MP3_33: U1.15 (B3), U3.15 (B3), U5.10 (25_IOB6A), U6.15 (B3)
MP4_33: U1.14 (B4), U3.14 (B4), U5.11 (26_IOB6B), U6.14 (B4)
MP5_33: U1.13 (B5), U3.13 (B5), U5.12 (29_IOB14A), U6.13 (B5)
MP6_33: U1.12 (B6), U3.12 (B6), U5.13 (30_IOB14B), U6.12 (B6)
MP7_33: U1.11 (B7), U3.11 (B7), U5.14 (31_IOB29A), U6.11 (B7)
MSEL0_33: U1.19 (CE), U5.15 (17_IOL49A_LED2)
MSEL1_33: U3.19 (CE), U5.16 (20_IOL51B_LED5)
MSEL2_33: U5.17 (19_IOL51A_LED4), U6.19 (CE)
unnamed: C2.2, J2.R, J2.T
unnamed: CON1.44 (SW1), CON1.46 (SW2)
unnamed: D1.2 (A), R1.2
unnamed: C1.1, J3.1
unnamed: C2.1, J3.2
unnamed 68: Q1.2 (B); also elsewhere on the board
unnamed 69: Q2.2 (B); also elsewhere on the board
RD: CON1.14 (~RD), U2.6 (A4)
RD_33: U2.14 (B4), U5.6 (15_IOL47A_LED0)
RESET: CON1.15 (~RESET), U6.6 (A4)
RFSH: CON1.6 (~RFSH), U6.7 (A5)
SLTSL: CON1.4 (~SLTSL), U2.8 (A6)
SLTSL_33: U2.12 (B6), U5.18 (18_IOL49B_LED3)
SOUNDIN: C1.2, CON1.49 (SOUNDIN)
WAIT: CON1.7 (/WAIT), Q1.3 (C)
WAIT_33: U2.4 (A2), U5.36 (42_IOB42B); also elsewhere on the board
WR: CON1.13 (~WR), U2.7 (A5)
WR_33: U2.13 (B5), U5.7 (16_IOL47B_LED1)

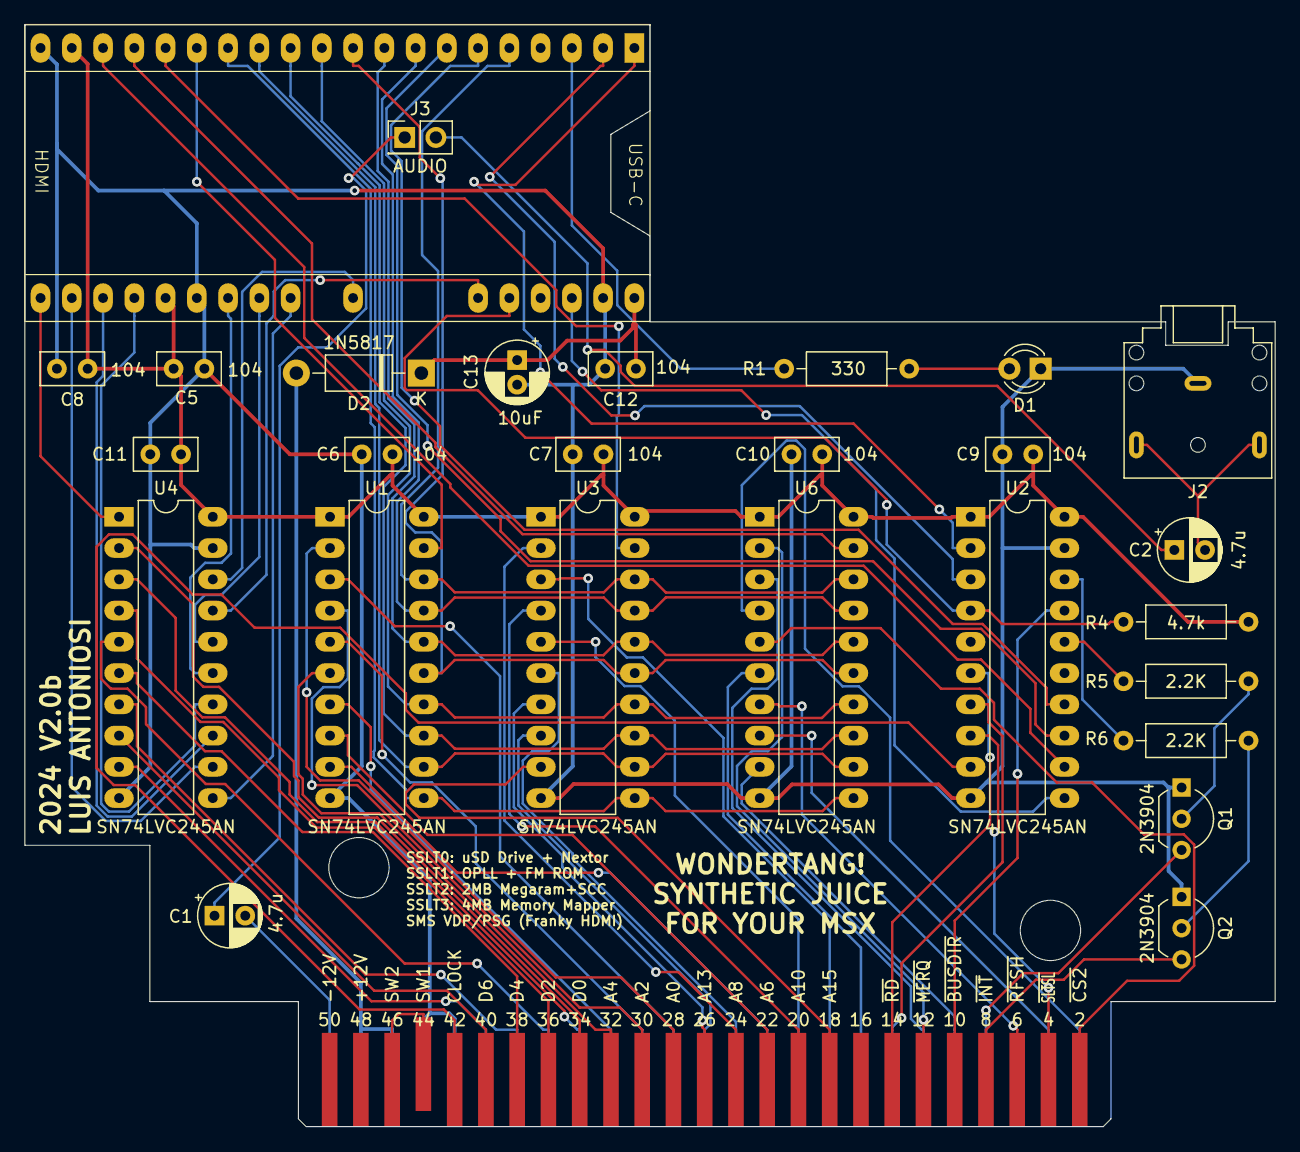
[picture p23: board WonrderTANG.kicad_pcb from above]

Board: 2 copper layers, 101.6 x 89.5 mm, 28 parts (0 on the bottom side), 81 nets.

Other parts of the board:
C13: 10uF; CP_Radial_D5.0mm_P2.00mm
R4: 4.7k; R_Axial_DIN0207_L6.3mm_D2.5mm_P10.16mm_Horizontal
R5, R6: 2.2K; R_Axial_DIN0207_L6.3mm_D2.5mm_P10.16mm_Horizontal

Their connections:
+3.3V: R4.1; also elsewhere on the board
+5V: C13.1; also elsewhere on the board
/INT_SW: R6.1; also elsewhere on the board
/WAIT_SW: R5.1; also elsewhere on the board
GND: C13.2; also elsewhere on the board
unnamed 68: R5.2; also elsewhere on the board
unnamed 69: R6.2; also elsewhere on the board
WAIT_33: R4.2; also elsewhere on the board

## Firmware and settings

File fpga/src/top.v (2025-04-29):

`define SMS
`define PSG
`define OPLL
`define SCC

module top(
    input   clk,
    input   s1,

    output led,

`ifdef SMS
    // hdmi output
    output            tmds_clk_p,
    output            tmds_clk_n,
    output     [2:0]  tmds_data_p,
    output     [2:0]  tmds_data_n,
`endif

    output hp_ws,
    output hp_din,
    output hp_bck,
    output pa_en,

    input clock,
    input rd_n,
    input wr_n,
    input sltsl_n,

    output int_n,
    output busdir_n,
    output wait_n,
    output datadir,

    inout [7:0] cd,

    input [7:0] mp,

    output [2:0] msel_n,

//    // flash
    output mspi_cs,
    output mspi_sclk,
    inout mspi_miso,
    inout mspi_mosi,
 
    // MicroSD
    output sd_sclk,
    inout sd_cmd,      // MOSI
    inout  sd_dat0,     // MISO
    output sd_dat1,     // 1
    output sd_dat2,     // 1
    output sd_dat3,     // 1
   
    // SDRAM
    output O_sdram_clk,
    output O_sdram_cke,
    output O_sdram_cs_n,            // chip select
    output O_sdram_cas_n,           // columns address select
    output O_sdram_ras_n,           // row address select
    output O_sdram_wen_n,           // write enable
    inout [31:0] IO_sdram_dq,       // 32 bit bidirectional data bus
    output [10:0] O_sdram_addr,     // 11 bit multiplexed address bus
    output [1:0] O_sdram_ba,        // two banks
    output [3:0] O_sdram_dqm       // 32/4
);

wire reset_ram_n;
wire reset_rom_n;
wire res_n_w;

    wire clk_w;
    BUFG(
    .O(clk_w),
    .I(clk)
    );


    reg [2:0] ff_cold_boot = 4;
    reg ff_res1 = 1;
    reg ff_res2 = 1;

    localparam CLK_FRQ              = 27_000_000;
    localparam BS_RES0              = 0;
    localparam BS_RES1              = CLK_FRQ/2;
    localparam BS_WARM              = CLK_FRQ;

    reg ff_s1n = 0;
    always @(posedge clk_w) ff_s1n <= ~s1;
    wire s1n_w = ff_s1n && ff_res1 && res_n_w;
    wire rgb;
    wire rgb_done;

    ws2812(
    .clk(clk_w),
    .rst_n(ff_s1n && res_n_w),
    .WS2812(rgb), // output to the interface of WS2812
    .done(rgb_done)
    );       

    reg [31:0] ff_bootstate          = BS_RES0;
    reg ff_wait = 1;
    reg ff_rgb_state = 0;

    always @(posedge clk_w) begin
        //ff_wait <= 1;
        if (rgb_done)
            case(ff_bootstate)
            BS_RES0: if (reset_ram_n) begin
                        ff_bootstate <= ff_bootstate + 1;
                        ff_res1 <= 0;
                        ff_res2 <= 1;
                        ff_wait <= 1;
                        ff_rgb_state <= 0;
            end
            BS_RES0+32: begin
                        ff_bootstate <= ff_bootstate + 1;
                        ff_res1 <= 1;
            end
            BS_RES1: if (reset_ram_n) begin
                        ff_bootstate <= ff_bootstate + 1;
                        ff_res2 <= 0;
            end
            BS_RES1+32: begin
                        ff_bootstate <= ff_bootstate + 1;
                        ff_res2 <= 1;
            end
            BS_WARM: begin
                        ff_res1 <= 1;
                        ff_res2 <= 1;
                        ff_wait <= 0;
            end
            default: begin
                        ff_bootstate <= ff_bootstate + 1;
            end
            endcase
    end
 


`ifdef SMS
    clk135 (
        .clkout(clk135), //output clkout
        .lock(clk135_lock_w), //output lock
        .reset(~s1n_w), //input reset
        .clkin(clk) //input clkin
    );
    BUFG (
    .O(clk135_w),
    .I(clk135)
    );

    assign rst_w = ~clk135_lock_w & ~clk108_lock_w;
`else

    assign rst_w = ~clk108_lock_w;
`endif

    clkp_108 (
        .clkout(clk108), //output clkout
        .lock(clk108_lock_w), //output lock
        .clkoutp(clk108p), //output clkoutp
        .clkoutd(clk_pa),
        .reset(~s1n_w), //input reset
        .clkin(clk) //input clkin
    );
    BUFG(
    .O(clk108_w),
    .I(clk108)
    );
    BUFG(
    .O(clk108p_w),
    .I(clk108p)
    );
    BUFG(
    .O(clk_pa_w),
    .I(clk_pa)
    );
    assign rst_n_w = ~rst_w;

    clockdiv2(
        .clk_src(clk108_w),
        .reset_n(clk108_lock_w),
        .clk_div(clk54)
    );

    BUFG(
    .O(clk54_w),
    .I(clk54)
    );

/// FLASH ROM LOADER - BIOS


reg ff_rom_wr = 0;
reg [7:0] ff_rom_dout;
reg [22:0] ff_rom_addr;

wire rom_wr_w;
wire [7:0] rom_dout_w;
wire [22:0] rom_addr_w;
assign rom_wr_w = ff_rom_wr;
assign rom_dout_w = ff_rom_dout;
assign rom_addr_w = ff_rom_addr;

reg ff_flash_rd = 0;
reg [23:0] ff_flash_addr = 24'd0;
reg [31:0] ff_flash_counter;

wire flash_data_ready_w;
wire flash_busy_w;

wire[7:0] flash_dout_w;
reg ff_flash_terminate = 0;
flash(
    .clk(clk_w),
    .reset_n(reset_rom_n),
    .SCLK(mspi_sclk),
    .CS(mspi_cs),
    .MISO(mspi_miso),
    .MOSI(mspi_mosi),
    .addr(ff_flash_addr),
    .rd(ff_flash_rd),
    .dout(flash_dout_w),
    .data_ready(flash_data_ready_w),
    .busy(flash_busy_w),
    .terminate(ff_flash_terminate)
);

reg [7:0] ff_flash_state = 8'd0;

localparam STATE_RESET          = 8'd0;
localparam STATE_READ_START     = 8'd1;
localparam STATE_READ_LOOP      = 8'd2;
localparam STATE_IDLE           = 8'd3;

wire flash_idle_w = (ff_flash_state == STATE_IDLE) ? 1'b1 : 1'b0;

always @(posedge clk_w, negedge reset_rom_n) begin
if (reset_rom_n == 0) begin
    ff_flash_state = STATE_RESET;
    ff_flash_rd <= 0;
    ff_rom_wr <= 0;
end else
    case (ff_flash_state)

        STATE_RESET: begin   // reset
            ff_flash_state <= STATE_READ_START;
            ff_flash_rd <= 0;
            ff_rom_wr <= 0;
            ff_flash_terminate <= 0;
        end

        STATE_READ_START: begin  // start read
            if (flash_busy_w == 0) begin
                ff_flash_addr <= 24'h100000;
                ff_rom_addr <= 23'h7fffff;
                ff_flash_rd <= 1;
                ff_flash_state = STATE_READ_LOOP;
                ff_flash_counter <= 128*1024;
            end
        end

        STATE_READ_LOOP: begin  // loop read
            if (flash_busy_w == 0) begin
                if (ff_flash_counter > 0) begin
                    if (~ff_flash_rd) begin

                        ff_flash_addr <= ff_flash_addr + 1;
                        ff_flash_counter <= ff_flash_counter - 1;
                        ff_flash_rd <= 1;

                        ff_rom_wr <= 1;
                        ff_rom_addr <= ff_rom_addr + 1;
                        ff_rom_dout <= flash_dout_w; 

                    end
                end else begin    
                    ff_rom_wr <= 0;
                    ff_flash_rd <= 0;
                    ff_flash_state <= STATE_IDLE;
                end
            end else begin
                ff_rom_wr <= 0;
                ff_flash_rd <= 0;
            end
        end

        STATE_IDLE: begin  // idle
            ff_flash_terminate <= 1;
        end

    endcase
end

//// DOT STATE

reg  [2:0] ff_msel_n;
reg  ff_dotena;

reg [2:0] dotena_state_ff;
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

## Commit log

2023-10-09 adding activity LED
2023-10-16 fix on wait line
    [WonrderTANG.kicad_pcb, WonrderTANG.kicad_sch]
2023-10-16 fix clock speed turboR
    [top.v]
2023-10-18 driver update
2023-10-19 kicad final version 1.01
    [WonrderTANG-B_Mask.gbr, WonrderTANG-B_Paste.gbr, WonrderTANG-B_Silkscreen.gbr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]
2023-10-28 kicad fixes
    fix shorted transistor add 10uf power line, moved cap to allow be placed horizontally
    [WonrderTANG-B_Mask.gbr, WonrderTANG-B_Paste.gbr, WonrderTANG-B_Silkscreen.gbr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]
2023-11-12 fix SCC, needs to compile disabling pinfilter FASTREAD
    fastread is required for hc-95 in turbo mode
    [top.v]
2023-11-23 Fix board audio
    audio pins were connected together
    [WonrderTANG-B_Mask.gbr, WonrderTANG-B_Paste.gbr, WonrderTANG-B_Silkscreen.gbr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]
2023-11-28 stl case, new rom
    [bottom.stl, top.stl]
2023-12-31 Update README with programming instructions, BOM and lock removal
2024-01-01 Update README.md
    add PCB Way link
2024-02-06 fixing audio to cart (Audio jumper) was set to wrong pin
    [WonrderTANG.kicad_sch]
2024-05-04 [kicad] Fix board edge clearance violation errors
    PCB edge connectors pad types are currently declared as SMD instead of
    Edge Connector which causes 49 board edge clearance violation errors
    when running the DRC (Design Rules Checker).
    Fix those by declaring the edge connectors pad types as Edge Connector.
    [WonrderTANG.kicad_pcb]
2024-05-04 [kicad] Fix CARTRIDGE_MSX footprint board edge clearance violation errors
    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
2024-05-04 [kicad] Fix silkscreen overlap between Q1 and R5
    [WonrderTANG.kicad_pcb]
2024-05-04 [kicad] Fix text thickness out of range errors for U5
    Fixes text thickness out of range errors for "HDMI"
    and "USB-C" texts of U5 by increasing text thickness
    from 0.1 to 0.15.
    [WonrderTANG.kicad_pcb]
2024-05-04 [kicad] Fix silkscreen clipped by solder mask for cartridge pads
    Text for pads 3 "CS12" and 4 "SLTSL" fall within one of the holes
    used to fix the cartridge board to the cartridge case.
    Make those texts visible again by reducing text width so that they
    do not extend into the cartridge board hole.
    [WonrderTANG.kicad_pcb]
2024-05-04 [kicad] show value for U4
    All SN74LVC245AN footprints show its value except U4.
    Fix that by adding its value to the silkscreen layer.
    [WonrderTANG.kicad_pcb]
2024-05-04 [kicad] Silkscreen updates for cartridge pads
    Mark active low signals BDIR,CS1,CS2,CS12,INT,IRQ,M1,MRQ,RD,RFSH,RST,SLTSL,WAIT,WR with a bar above them.
    Add voltage suffix V to +5, +12 and -12 signals.
    Add pad number to pad 43.
    Add pad number to pad 44.
    Name each SW pad with its own names SW1 and SW2.
    Rename BDIR to BUSDIR.
    Rename CLK to CLOCK.
    Rename RST to RESET.
    Rename SND to SOUNDIN.
    [WonrderTANG.kicad_pcb]
2024-05-04 [kicad] Fix /CART_5V net width
    Update the PCB to bring /CART_5V in sync with the schematic.
    Apply the power netclass width to /CART_5V as it is currently using a
    smaller width than the rest of power nets (from the cartridge pads to the
    D2 diode).
    Add clearance when needed to account for the increase in net width.
    [WonrderTANG.kicad_pcb]
2024-05-10 fix audio source clk
    [top.v]
2024-05-11 soound improments
    removing filters
    removing psg from cartridge sound port
2024-05-11 swap audio outputs for version 1.0c
    [top.v]
2024-05-12 adding filters back
2024-05-22 fpga: improve signal mux
    The WonderTANG uses a multiplexing scheme to read 24 signals using just
    8 pins through three 74LVC245 ICs.
    The multiplexing scheme is driven by a ~108MHz clock (~9.25ns period)
    using the following schedule based on a 8 cycle plan:
    - the first cycle is used to select A0-A7 signals and enable signal
    propagation (which is Ten=~4.4ns for the 74LVC245)
    - during the second cycle A0-A7 data can be read consistently
    - the third cycle is used to select A8-A15 signals and enable signal
    propagation
    - during the fourth cycle A8-A15 data can be read consistently
    - the fifth cycle is used to select MERQ,IORQ,CS1,CS2,RESET,RFSH,CS12
    and M1 signals and enable signal propagati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
    [top.v]
2024-05-24 fix scc merg line
    [top.v]
2024-05-25 version d schematic
    [WonrderTANG.kicad_sch]
2024-05-25 Revert "version d schematic"
    This reverts commit 586f92a0309d7defb717df5fd5272d4bcb2072a4.
    [WonrderTANG.kicad_sch]
2024-05-26 fix opll and some audio changes
    [top.v]
2024-05-26 New PCB Version 1.0.2d
    A new firmware inverting the INT outpult needs to be submitted.
    [WonrderTANG-B_Mask.gbr, WonrderTANG-B_Paste.gbr, WonrderTANG-B_Silkscreen.gbr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]
2024-06-19 version 2.0b
    [WonrderTANG-B_Mask.gbr, WonrderTANG-B_Paste.gbr, WonrderTANG-B_Silkscreen.gbr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]
2024-06-19 fix hdmi audio / sms
    [top.v]
2024-06-19 fix led
2024-06-20 removing volume control not working
    [top.v]
2024-06-20 document board revisions and bitstreams
2024-07-05 shutdown rgb led reduce noise
    [top.v]
2024-07-05 reset rgb led on msx reset button
    [top.v]
2024-07-08 new v2.0 STL case
    [wonderTANGv2-cart-bottom.stl, wonderTANGv2-cart-top.stl]
2024-07-09 make cartridge 1mm thinner
    [wonderTANGv2-cart-bottom.stl, wonderTANGv2-cart-top.stl]
2024-12-14 incread clock frq on clock pin
2025-04-29 fix some meta-stability - SOFARUN still has SCC broken
    [top.v]
